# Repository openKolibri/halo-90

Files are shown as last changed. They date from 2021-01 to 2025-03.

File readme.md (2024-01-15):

![wornDynamic]

# HALO-90
A distinct ring of light. An ethereal glow. Patterns that ebb and flow to the music. Ninety lights. All controllable. Powered by a common coin cell. An engrossing look with retro vibes and a modern touch. This is HALO-90.

![presentedCase]

The *HALO* product series, in which these earrings ([HALO-90]) are the first item, is a fully open source electronic jewelery line. It is designed with elegance and wearability in mind. `90` refers to the ninety individually controllable LEDs on the earring face. The built-in compute power is also suitable for creating complex light shows.

This is the technical manual for anyone wanting to modify, hack, remix, or program their own light patterns onto the earrings. The manual goes into fine detail about construction, assembly, and firmware which should encompass all basic knowledge.

## Table of Contents
* [Design](#design)
  + [Hardware](#hardware)
    - [LEDs](#leds)
    - [Microcontroller](#microcontroller)
    - [Battery](#battery)
    - [Microphone](#microphone)
    - [Button](#button)
    - [IMU](#imu)
    - [Passives](#passives)
    - [Alignment Pins](#alignment-pins)
    - [Connectors](#connectors)
  + [Case](#case)
    - [FDM Printed](#fdm-printed)
    - [Cast](#cast)
      * [Mould Master](#mould-master)
      * [Silicone Mould](#silicone-mould)
    - [Stone Casting](#stone-casting)
    - [Magnets](#magnets)
* [Firmware](#firmware)
  + [Modes](#modes)
    - [Dynamic](#dynamic)
    - [Halo](#halo)
    - [Sparkle](#sparkle)
    - [Power Managment](#power-managment)
  + [LED control](#led-control)
  + [Compiling](#compiling)
    - [Ubuntu/WSL](#ubuntu-wsl)
    - [Arch](#arch)
  + [Flashing](#flashing)
    - [Windows](#windows)
    - [Linux](#linux)
* [Absolute Maximum Ratings](#absolute-maximum-ratings)
* [Guaranteed Ratings](#guaranteed-ratings)
* [Manufacturing](#manufacturing)
  + [BOM](#bom)
  + [PCB](#pcb)
  + [PCB Assembly](#pcb-assembly)
    - [Assembly Detail Pictures](#assembly-detail-pictures)
    - [Potential Alternates](#potential-alternates)
  + [Physical Assembly](#physical-assembly)
  + [Production Scaling](#production-scaling)
    - [Case](#case-1)
* [Programmer](#programmer)
* [Artwork](#artwork)
* [Inventory and QC](#inventory-and-qc)
* [Packaging](#packaging)
* [Shipping](#shipping)
* [Safety](#safety)
* [Certifications](#certifications)
* [Licence](#licence)
* [Attribution](#attribution)
  + [Fonts](#fonts)
  + [Libraries](#libraries)
* [ToDo](#todo)

## Design
Design was always a core objective from the very beginning. It *has* to look good. Even more importantly, it must also be functional, as it is a piece of jewelry people are going to wear. If it looks too complex or it's too difficult to use, no one will want to wear it. Comfort was also major goal, as heavy earrings are painful to wear for extended amounts of time, no matter how stunning they are. It's simply not worth the pain.

![render]

The design had to allow for a variety of LED patterns with a range from subtle to attention grabbing. Sensors were added to make light patterns more personal and reactive to the local environment, such as the muted audio responsive pattern. At one moment, befit for a quiet restaurant and later a flashy wide pattern at a concert.

| Audio | Halo | Sparkle |
| --- | --- | --- |
| ![PAT-audio] | ![PAT-halo] | ![PAT-sparkle] |

### Hardware
The electronics are kept minimal for cost reduction and manufacturing simplicity with pads and routing done for all but the IMU and its pull-up resistors. They are not mounted, because there is no firmware support for that and it yields a lower cost variant. The design is done in [KiCad] 5.99 (nightly) and will be ported and set in the stable version. All components and libraries are embedded in the project. 

![IMG-schematic]

The schematic is also available as a [pdf][PDF-schematic]. The layout is done partially programmatically using text manipulation and template stamping using JavaScript and node and then finished up by hand in KiCad. The code is available [here][nodeHaloBuilding].

#### LEDs
There are 90 LEDs that make up the ring, All are regular `0402` red diodes. All the cathodes (K/-) face towards the center of the board, and are placed at `4°` intervals. The LEDS are charlieplexed with ten lines providing individual control. They are run at as high of a current as the battery's internal resistance and GPIO max current allows, so no resistors are used. The red LEDs, with their `2.0 V` - `2.6 V` forward voltage, permits maximizing battery usage
We are using [BL-HUB37A-AV-TRB], because it is low cost and has high availability across multiple vendors in China, but any `0402` LED with a V<sub>f</sub> below `2.7 V`, should yield an equivalent battery life.

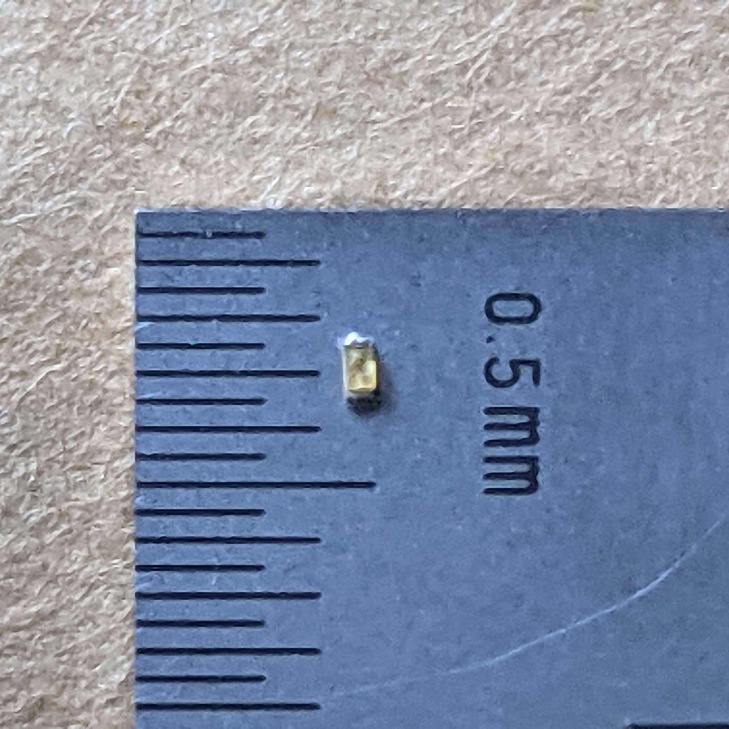
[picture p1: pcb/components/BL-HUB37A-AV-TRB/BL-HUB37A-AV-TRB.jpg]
IMG-BL-HUB37A-AV-TRB


#### Microcontroller
*STMicroelectonics's* [STM8L151G4] acts as the main controller for the earring. The low power microcontroller has a wide range of peripherals, a long expected production life, and low cost and availability in high quantities. Running at its max speed of `16 MHz` is able to easily charliplex the 90 Leds at over `1 kHz`. The `12b ADC` is used to readout the microphone and has plenty of flash (up to `32k`) to store an assortment of light patterns or complex processed designs.

![IMG-STM8L15xxx]

#### Battery
*Linx Technologies's* aptly named [BAT-HLD-001] is a stamped die-cut sheet-metal battery-holder that is as low profile as possible. It is sized for a `CR2032` lithium cell. The metal acts as the anode while the pad on the PCB is the cathode. Battery life varies based on what threshold for brightness you are content with. Over its lifetime, the internal resistance of the battery increases and the voltage decreases. This means that the current possible also decreases and thus the brightness.

![IMG-BAT-HLD-001]

#### Microphone
The microphone selection was rather difficult due to a lack of specifications available with amplified MEMS microphones. *Knowles* [SPW2430HR5H-B] was selected, as it seemed reasonable and could be tested with Adafruits breakout board fairly easily.

![IMG-SPW2430HR5H-B]

Using a built-in amplified MEMS microphone decreases the number of component placements and simplifies layout and verification, at the expense of not having instrumentation knowledge of your audio response.

#### Button
*C&K* [KXT3] series provides ultra low profile miniature tactile switches and we chose `KXT311LHS`, with a low actuation force of `100g`. It can be easily pressed with the edge of your nail, or a bit less comfortably with the back.

The button provides the functionality of changing light patterns by pressing and triggering it into a low power sleep mode by holding for `500 ms`. Completely available as an interrupt to the microcontroller, so other uses can be implemented. 

![IMG-KXT3]

#### IMU
[LSM6DSM] is a 6DOF IMU with a three-axis accelerometer and three-axis gyroscope by *STMicroelectronics*. It communicates over I2C and is connected to the hardware I2C peripheral in the microcontroller. It allows a fast data stream at very low power. It also has additional low power modes and the ability to wake the main microcontroller over interrupt with the routed interrupt pin. 

![IMG-LSM6DSM]

#### Passives
There are three passives (five if the IMU is populated) that can be of any tolerance. There are two `1 uF` and `0.1 uF` decoupling capacitors and one `10k` pull-up on the reset of the processor. The two IMU pull-ups are `10k` I2C pull-ups.

#### Alignment Pins
There are four tooling holes/alignment pins that can be used for add-ons. They are `1.152 mm` (`45.35 mil`) in diameter and are placed `2.8 mm` and `5.5 mm` from the center.

![alignmentPins]

 The earring is `24 mm` in diameter, has a mass of `5.207 g` (`2.135 g` without the battery) and the top eyelet extends `2 mm` extra, yielding a bounding box of `24 mm x 26 mm x 6.36 mm`.

![mass]

#### Connectors
The only connectors on the board are six `⌀ 1 mm` copper circles that are exposed as contacts for spring pins. They are placed evenly across the board so it receives balanced forces from the custom programmer (or testing jig).

| Labels | Dimensions |
| --- | --- |
| ![pgrmPads] | ![pgrmPlacement] |

The labeled pins have their descriptions in the table below.

| Pin  | Description |
| ---- | --- |
| 3V0  | Connected to Batt+ and power net |
| GND  | Connected to ground net |
| TX | GPIO PB2 for serial out | 
| RX | GPIO PB4 for serial in | 
| RST  | Active low, 10k pull-up | 
| SWIM | Programming interface | 

### Case
The case holds the earrings and two cells in its cavities. This allows for the storing and organizing of at least 36 hours of available runtime. The earring case consists of two pieces held together with magnets. The cavities inside the case hold all components securely so that they do not rattle. The earrings are displayed beautifully when the case is opened.

![cases]

The case is designed in CAD and made to house two earrings (with or without batteries inserted) as well as two additional batteries. All of the edges are filleted and the closed case is comfortable when held. One corner is chamfered which makes it easier to align both pieces together in the correct orientation, and the magnets are oriented to resist trying to close it whenever the directionality does not match. It also provides a very satisfying tactile click when they align and close.

![caseRender]

#### FDM Printed
The first sets of cases are made of 3D printed plastic PLA. The top and bottom have bold contrasting colors that uniquely identify the brand. They are printed with a `20%` gyroid infill and at `200 um` layer height. The 3D models must be scaled up to `100.2%` to account for PLA shrinkage. 

![caseFDM]

#### Cast
For a more bold and distinctive style with a pebble or smooth seashell-like finish, casted cases provides an air of luxury using distinctive materials.

![caseBatch]

##### Mould Master
Moulding masters were made using the same 3D printed designs, printed at an `80 um` layer height, and then repeatedly filled, primed, and sanded with `P400` to `P3000` grit sandpaper on top of a glass plate to keep the straight faces square. This fills all of the air gaps and allows for a very smooth finish. It is then buffed to a shine with nail buffer sponges.

![caseMaster]

##### Silicone Mould
A platinum cure shore `A20` silicone rubber (Troll Factory [TYP-1]) is used to make a mould of the master. This has an accuracy of `~2 um` so it's able to reproduce a surface finish. Since the back is flat, an open-faced mould is made. The part, as well as the walls, are held in place with [Quakehold] museum wax, and mixing the exact amount of silicone needed (based on a CAD model) means a high yield. After curing, the mould box walls are cut off and the master is demoulded, yielding a silicone mould.

![caseMould]

#### Stone Casting
The mould can be cast with various materials, including other silicones, polyuretane, rubbers, and resins. In our case, we used plaster. We are using high compressive strength *Ernst Hinrichs* [Sockelgips FL] `Type-4 low expansion dental plaster`. These plasters have a thixotropic agent that allows them to flow better, which means that they mix thinner and reproduce in finer detail. Applying a surfactant to the mould, mixing with distilled water, and using a vibrating table produces castings with fewer bubbles. The back is roughly leveled off and set to cure. The part is demoulded and the back is hand finished with `P320-P3000` grit sandpaper.

![caseCasting]

After 24 hours, the part has cured to its final hardness and has dried out completely. It can then be processed further with magnets and dye. 

#### Magnets
The magnets are `6 mm x 1 mm` `N52` neodynium magnets that are glued in with UHU Max Repair Extreme adhesive. They are coated in `Ni-Cu-Ni`, at around `12 um`. The magnets are a very tight fit in their countersinks and are glued in to fit securely. They have a fixed orientation between both parts made, so swapping tops or bottoms with other sets is possible. There are few adhesives that work well when bonding two materials together that are already difficult to glue.

![6x1-magnets]

Magnets are installed using a gluing jig. One jig for the top and one for the bottom. Both jigs have magnets installed to correct for orientation when gluing. The jigs also have a matching chamfer which prevents the wrong part from being placed or placing the part backwards by accident.

![magnetsGlued]

The two jigs are color-coded as well. Adhesive is dispensed into the wells and the magnet is dropped, which automatically orients itself with the jig magnet. It can then be removed and set to cure.

![magnetJig]

## Firmware
The firmware is coded at the register level in C. The code is fully interrupt-based and performs quite efficiently. The toolchain is simple and built on open source tools. This makes it harder to code, but allows for significant optimization.
 
### Modes
There are multiple modes available on the halo earring that can be switched through when pressing the button. Each press of the button cycles to the next mode, eventually circling back around.

| Audio | Halo | Sparkle |
| --- | --- | --- |
| ![GIF-audio]  | ![GIF-halo] | ![GIF-sparkle] |

#### Dynamic
The mode selected on startup is the audio-based dynamic mode. During every ADC cycle it reads the analog value and projects the audio waveform amplitude, based around a moving point on the ring with wrap around.

![PWR-audio]

Power profile readings show no correlation with audio level, and an `11.71 mA` power consumption with `105 uA` standard deviation. Projected battery life with a `220 mA` CR2032 cell is ~18.8 hours.

#### Halo
In the HALO mode, the entire light ring is lit. This is done through interlacing the illumination of each LED. The deep sleep auto wakeup timer is set to wake up every two clock cycles of the low speed `32 kHz` oscillator. On every wake, it changes to illuminate the 13th following LED, wrapping around at 90.

```c
setLed((prevLed + 13)%90);
```

This allows for a cleaner and more consistent scan over the entire halo ring since 13 is the greatest integer factor (besides 91), for all of the LEDs to be turned on evenly around the ring. Greater spacing causes *frames* to interlace with one another, resulting in a cleaner visual experience.

![PWR-halo]

Power profile readings show a `10.88 mA` power consumption with `60 uA` standard deviation. Projected battery life with a `220 mA` CR2032 cell is ~20.2 hours.

#### Sparkle
Sparkle mode is the best for minimal power draw and is implemented in a single line of code. At `~320 Hz`, the processor wakes from deep sleep and runs the selection of which LED to light (if any).

```c
rand()%15 ? ledLow(prevLed) : setLed(rand() % 90);
```

Given a 1/15 chance, a random LED will light up. Otherwise, any previously lit LEDs will be turned off. This results in a more visually pleasing pattern over just randomly lighting LEDs, which produce sharper bursts of light. Since the processor is only awake `0.002%` of the time, and the LED has a chance of being on only `6.6%` of the time, the power consumption is quite minimal. 

![PWR-sparkle]

Power profile readings show a `2.01 mA` power consumption with `327 uA` standard deviation. Projected battery life with a `220 mA` CR2032 cell is ~109.5 hours, (over 4.5 days).

#### Power Managment
Pressing and holding the button for `500 ms` will turn off all LEDs and put the cpu into deep sleep mode. In this mode the current draw is around `15 uA` and the only wake interrupt is the button press.

![GIF-boot]

Pressing and holding the button will show a boot-up animation that lights up in a ring around the face. Holding the button until it makes a full revolution, about one second, will trigger a software reset of the halo, turning it back on.

### LED control
Since the LEDs are configured in a charlieplex array, only one LED can be on at a time. Some optimization can allow multiple LEDs to light simultaneously, but at a cost of consistency in brightness and power draw. There are two low-level functions that can turn a individual LED on or off, as well as a helper function that remembers the last LED and turns it off before turning on the next one.

```c
void setLed(uint8_t led);
void ledHigh(uint8_t led);
void ledLow(uint8_t led);
```

The function to get the column and row from the LED number is shown below:
```c
uint8_t col = led / 9;
uint8_t topElements = 9 - col;
uint8_t row = 9 - (led % 9);
if (topElements <= (9 - row)) {
  row--;
}
```

To turn the LEDs off, the column and row are both set to high impedance. To turn it on, the column is set high and the row is set low.

The previous LED *must* be turned off before lighting up the next LED or else there is a risk of damaging the electronics. It is recommended to only use the `setLed` and `ledLow` functions.

### Compiling
Compiling is done with the [SDCC] ("Small Device C Compiler") and the included makefile.

As an example, the following steps are given for some systems but should easily be transferable to the distro of your choosing. The requirements are `make` and `sdcc`. They should both be available in the path. Once installation is completed, running `make` will generate the `halo.ihx` file, which is the binary to be flashed.

```bash
make
```

#### Ubuntu/WSL
```bash
sudo apt install -y make
sudo apt install -y sdcc
```
#### Arch
```bash
sudo pacman -S make
sudo pacman -S sdcc
```

### Flashing
Some form of flashing software is required, along with a programmer that can program over the `SWIM` protocol. We are using third party `STLink-V2` clones, because the form factor of the genuine programmer is difficult to use and newer programmers do not support `SWIM`.

#### Windows
`STVP_CmdLine` is required as the flashing software and comes with the software package [ST Visual Programmer]. This needs to be installed and `c/Program Files (x86)/STMicroelectronics/st_toolset/stvp/STVP_CmdLine.exe` needs to be added into the path.

Once it's installed, it can be run with the following flags. Preferably in WSL but should also be possible in CMD or PS.

```bash
STVP_CmdLine.exe -Device=STM8L15xG4 -FileProg=halo.ihx -verif -no_loop -no_log
```

It is also incorporated into the make file and can be run with the following:

```bash
make flash
```

#### Linux
[STM8 Flash] is an open source `SWIM` compatible flashing utility for linux. The tool is built from source. Short instructions are written below.

```bash
git clone https://github.com/vdudouyt/stm8flash.git
cd stm8flash
make
sudo make install
```

Flashing can then be done with the following command:

```bash 
stm8flash -cstlink -pstm8l151 -w halo.ihx
```

It is also incorporated into the make file and can be run with the following:

```bash
make flash
```

## Absolute Maximum Ratings

| Parameter | Min  | Max | Unit |
| --- | ----:| ---:| ---- |
| Battery Voltage | -0.3 | 3.6 | Volt |
| Temperature |  -40 |  85 | °C |
| Power Draw |  15u | 25m | Amp  |

## Guaranteed Ratings

| Parameter | Min | Max | Unit |
| --- | ---:| ---:| ---- |
| Battery Voltage | 1.8 | 3.6 | Volt |
| Operating Temperature  | -20 |  50 | °C |
| Storage Temperature | -40 |  85 | °C |

The earrings should be fine to leave in a hot car (although the 3D printed plastic case could warp). If you are outside of these ratings, take care of yourself, you are either freezing or at risk of heat stroke. The earrings will be fine.

## Manufacturing
Although taking on novel uses of materials, the ability to manufacture at scale was always a primary focus. Parts were selected with strong supply chains and alternatives. Layout was designed with generous rules to accommodate for as many fabs as possible and the number of unique components was minimized. The microphone and battery holder are from single vendors but they have proven track records and well-known supply chains. Alternatives to be tested are still proposed.

### BOM
The BOM was selected with parts that are common to the high-volume Chinese manufacturing market, have strong supply chains, and have many alternatives available in case a supplier stops manufacture or supply dips occur. The number of unique parts was kept to a minimum and the maximum amount of features can be implemented with "free" pins, like the programming SMD pads. The table of BOM is shown below.

| REF | QTY | Manufacturer | MPN | Description |
| --- | ---:| --- | --- | --- |
| D1-D90 |  90 | Brightled | BL-HUB37A-AV-TRB | LED: RED 627-637nm 50mcd@20mA 0402  |
| U1 | 1 | STMicroelectronics | STM8L151G4U6 | MCU: 8b 16MHz 16k Flash UQFN-28-4x4 |
| MK1 | 1 | Knowles Electronics | SPW2430HR5H-B | MIC: Omni Si-Sonic 3.1x2.5x1.0mm |
| BT1 | 1 | Linx Technologies | BAT-HLD-001 | BAT: CR2032 Cell Holder |
| S1 | 1 | C&K | KXT311LHS | SW: Low Profile 3x2x0.6mm 100gf |
| R3 | 1 | Uniroyal | 0402WGF1002TCE | RES: 10k 5% 1/16W 0402 |
| C1 | 1 | Samsung Electro-Mechanics | CL05B104KO5NNNC  | CAP: MLCC 100nF 16V 0402 |
| C2 | 1 | Samsung Electro-Mechanics | CL05A105KA5NQNC  | CAP: MLCC 1uF 25V 0402 |

The [csv][BOMcsv] is provided with the sources.

### PCB
There is a single PCB. Although still common, some of the more precise requirements were needed to end up with a printed circuit board small enough.

| Parameter | Value | Unit |
| --- | -----:| ---- |
| Height | 26 | mm |
| Width | 24 | mm |
| Layers | 4 | ul |
| Copper | 1.0 | oz |
| Copper Inner | 0.5 | oz |
| Thickness | 1.0 | mm |
| Material | FR4 | ul |
| Min Drill | 0.2 | mm |
| Trace Size | 5/5 | mil  |
| Mask | Black | ul |
| Silk | White | ul |
| E-Test | Yes | ul |
| Surface Finish | ENIG  | ul |

The PCB has four layers.

| Front | Inner 1 | Inner 2 | Back |
| --- | --- | --- | --- |
| ![Layer0] | ![Layer1] | ![Layer2] | ![Layer3] |

### PCB Assembly
The whole board can be pick and placed. The table below shows some data that might be needed when requesting a quote.

| Parameter | Value |
| --- | -----:|
| Unique Parts | 8 |
| SMD Parts | 8 |
| Placements | 97 |
| Solder Joints | 222 |
| Front Components  | 96 |
| Back Components | 1 |

The smallest components are `0402` LEDs, and all parts can survive normal lead-free re flow profiles. The microphone is open port MEMS so do not wash, clean, or expose it to ultrasonic vibrations (datasheet has further requirements).

#### Assembly Detail Pictures

| Assembly | Front |
| --- | --- |
| ![assembly] | ![front] |

| Front Detail | Back Detail |
| --- | --- |
| ![frontDetail] | ![backDetail] |

| Front ISO | Back ISO |
| --- | --- |
| ![frontIso] | ![backIso]  |

#### Potential Alternates
Some alternates have not been tested, but their specifications match.

| Stated | Alternative | Tested |
| --- | --- | --- |
| SPW2430HR5H-B | ZILLTEK ZTS6016  | No |
| BAT-HLD-001 | MY-2032-08 | No |
| STM8L151G4U6 | STM8L151G6U* | Yes |

*To be updated when I can get stock or have to switch suppliers*

### Physical Assembly

The earwire is attached with jewelry pliers through the hole. The 1mm hole is made for up to `0.8 mm` wire over `20 ga`. Gold plated french hooks are used. these are commonly available as jewelry findings.

![IMG-frenchEarwire]

### Production Scaling Boards
The board can be hexagonally packed into a panel with tiny tabs since it's held on all sides. To increase production efficiency, only one side can be PnP and the battery holder is added afterwards by hand.

![hexPackedPanel]

#### Production Scaling Cases
The master moulds can create secondary masters out of resin which could then be used to make gang moulds, allowing for multiple castings in parallel. 

![gangMoulds]

## Programmer
The programmer has a hole at the top to allow a pin to push the button for testing.

![programmer]

The 3D printed base holds the board in place while the PCB is held to it with 3mm heat set inserts. The PCB acts as a compliant mechanism providing down pressure while still allowing it to be flexible enough to lift. 

The programmer uses *Mill-Max* ‎‎‎[0965-0-15-20-80-14-11-0]‎ spring pins on a PCB that matches exactly with the six pads on the face of the board. 

![springPins]

The top part is lifted up and the assembled board is slipped in. The spring force from the PCB pushes back down on to the pads and can then be left for programming and debugging.

## Artwork
The design and layout, the main artwork on the board and the PCB layers and traces, are *NOT* protected Intellectual Property ("IP"), see LICENSE files for appropriate details.
Any additional writing or images such as the Kolibri bird, copyright and designer notices, and certifications *ARE* considered protected IP and notice is given that they are protected by all applicable IP laws.
The below "Getting Started" card also has artwork which is considered protected IP and is copyrighted with all rights reserved.

| Front | Back |
| --- | --- |
| ![cardFront] | ![cardBack] | 

## Inventory and QC
Inventory can be managed with QR coded serialized tags. This serialization provides better quality control because it allows failure analysis and tracking in cases of issues traceable to batch and assembly.

## Packaging
We are packaging and shipping in `14 cm x 17 cm` padded envelopes with branded stampings. These fit under the Warenpost requirements and allow international shipping. The envelopes are verified to be under `3 cm` before dispatching. Custom labeled sleeves will be used for retail packaging.

## Shipping
The labels are printed with CN22 on the harmonized label schedule.

Lithium cells have special requirements for shipping. With air mail, small cells (up to four) are packaged securely and may be sent with the product. A note (`Lithium metal batteries in compliance with Section II of PI969`) is required on the packaging, but no warning label is mandatory.

For international shipping, the HS code `7117.90.0000	Imitation Jewlery other` is used.

## Safety
The edges are fully routed when possible or finished afterwards. The PCB is made from fiberglass so care must be taken because it can have abrasive edges. Clear coat nail polish can be applied to round and soften the edges without changing how it looks.

The `CR2032` cells are quite safe, as they have only very small traces of lithium, and have a fairly high internal resistance. However, they must still be disposed of responsibly. `LIR2032` or other rechargeable 2032 cells should *not* be used because they have a higher voltage outside of the guaranteed parameters and significantly lower capacity (under 25%).

If the battery is placed in backwards, it will drain over time because there is no reverse polarity protection. It will heat up but should not damage anything, due to high internal resistance limiting the discharge. The low voltage, `3.0 V`, as well as the currents used pose very little risk.

The printed circuit boards are assembled in a lead-free process, and all components are `ROHS` certified.

## Certifications
Certifications take time and effort but will make a better product by guaranteeing its safety to users and letting them use it in other projects. The table below shows the order in which we will obtain certifications.

| Certifying Authority | Status |
| ---| --- |
| OSHW | [DE000103] |
| CE | No  (Self Certification)  |
| FCC | No  (Self Certification)  |
| WEEE | No  (yearly fee) |

## Licence
The product was designed by Sawaiz Syed for Kolibri. Kolibri owns all protected IP. Everything that is not otherwise stated as being protected IP (e.g. firmware, PCB design, documentation) is released under permissive copyleft licenses.

| Sector | License | Version |
| --- | --- | ---:|
| Hardware | [CERN-OHL-S] | 2.0 |
| Firmware | [GNU GPL] | 3.0 |
| Documentation | [CC BY-SA] | 4.0 |

Files of all licenses are required with the distribution of files. All files are available in easy-to-modify formats for remixing. 

---
#### Please purchase original products from [Kolibri] to support further products, design, and research :)

---

## Attribution
- Make
- [SDCC]
- KiCad
- [STM8Flash]
### Fonts
- [Nunito]
- [IBM PLEX Mono]
- [DejaVu] 
### Libraries
- [STM8 Headers] Copyright (c) - 2020 Georg Icking-Konert

## ToDo
- [ ] Led sometimes remains on after shutdown
- [ ] Randomly HALO pattern forms high low pattern 

<!--                       References                                      -->
<!-- Files -->
[BAT-HLD-001]:                ./pcb/components/BAT-HLD-001/BAT-HLD-001.pdf
[BL-HUB37A-AV-TRB]:           ./pcb/components/BL-HUB37A-AV-TRB/BL-HUB37A-AV-TRB.pdf
[KXT3]:                       ./pcb/components/KXT3/KXT3.pdf
[LSM6DSM]:                    ./pcb/components/LSM6DSM/LSM6DSM.pdf
[SPW2430HR5H-B]:              ./pcb/components/SPW2430HR5H-B/SPW2430HR5H-B.pdf
[STM8L151G4]:                 ./pcb/components/STM8L15xxx/STM8L15xxx.pdf
<!-- Links -->
[HALO-90]:                    https://openkolibri.com/hlo/90
[KiCad]:                      https://kicad.org/
[ST Visual Programmer]:       https://www.st.com/en/development-tools/stvp-stm32.html
[Quakehold]:                  https://www.quakehold.com/collectibles.html
[TYP-1]:                      https://trollfactory.de/produkte/silikon-kautschuk/haertegrad-shore/weich-shore-a25/7044/tfc-silikon-kautschuk-typ-1-abformsilikon-weich-1-1-nv-troll-factory-rtv
[0965-0-15-20-80-14-11-0]:    https://www.mill-max.com/products/pin/0965
[Sockelgips FL]:              https://www.hinrichs-dental-shop.de/sockelgips-fl-p-1469.html
[Kolibri]:                    https://openkolibri.com/
<!-- Internal Links -->
[PDF-schematic]:              ./docs/design/hardware/schematic.pdf        
[nodeHaloBuilding]:           ./pcb/halo.js
[BOMcsv]:                     ./pcb/bom.csv
<!-- Intro -->
[wornDynamic]:                ./docs/intro/wornDynamic.gif                              "Worn earring reacting to music Model: Greta"
[presentedCase]:              ./docs/intro/haloSetDisplay.jpg                           "Pair of earings in holder"
[render]:                     ./docs/render.jpg                                         "Render of earrings showing propertions"
<!-- Design -->
[PAT-audio]:                  ./docs/patterns/audio.gif                                 "Worn animation of audio pattern"
[PAT-halo]:                   ./docs/patterns/halo.gif                                  "Worn animation of halo pattern"
[PAT-sparkle]:                ./docs/patterns/sparkle.gif                               "Worn animation of sparkle pattern"
<!-- Hardware -->
[IMG-schematic]:              ./docs/design/hardware/schematic.png                      "Image of schematic"

<!-- Components -->
[IMG-BAT-HLD-001]:            ./pcb/components/BAT-HLD-001/BAT-HLD-001.jpg              "CR2032 Battery Holder"
[IMG-BL-HUB37A-AV-TRB]:       ./pcb/components/BL-HUB37A-AV-TRB/BL-HUB37A-AV-TRB.jpg    "0402 Red LED"
[IMG-KXT3]:                   ./pcb/components/KXT3/KXT3.jpg                            "Miniature low profile button"
[IMG-LSM6DSM]:                ./pcb/components/LSM6DSM/LSM6DSM.jpg                      "6 axis IMU"
[IMG-SPW2430HR5H-B]:          ./pcb/components/SPW2430HR5H-B/SPW2430HR5H-B.jpg          "MEMS Microphone"
[IMG-STM8L15xxx]:             ./pcb/components/STM8L15xxx/STM8L15xxx.jpg                "Low power microcontroller"
[IMG-frenchEarwire]:          ./pcb/components/frenchEarwire/frenchEarwire.jpg          "Gold plated french earwire"
<!-- Magnets -->
[6x1-magnets]:                ./docs/components/magnets.jpg                             "6mm x 1mm N53 disc mangents"
[magnetsGlued]:               ./docs/assembly/jigsGlue.jpg                              "Mangents glued using the jig"
[magnetJig]:                  ./docs/assembly/jigs.jpg                                  "Jigs used to glue magnets into place in the correct orentation"
<!-- Connectors and pads -->
[alignmentPins]:              ./docs/connectors/pinDim.jpg                              "Holes for tooling and jig alginment"
[mass]:                       ./docs/connectors/mass.jpg                                "Halo and battery on scale for measuring mass"
[pgrmPads]:                   ./docs/design/hardware/pgrmPads.png                       "Labeling of the programming pads"
[pgrmPlacement]:              ./docs/design/hardware/pgrmPlacement.png                  "Dimentions of the programming pads"
[springPins]:                 ./docs/components/springPin.jpg                           "Spring pin for programing"    
<!-- Case -->
[caseBatch]:                  ./docs/case/batch.jpg                                     "Batch of cast cases"
[caseRender]:                 ./docs/case/caseRender.jpg                                "Render of case looking at coloring options"
[cases]:                      ./docs/case/cases.jpg                                     "View of diffrent colour and dye trials"
[caseCasting]:                ./docs/case/casting.jpg                                   "Closeup of cast case"
[caseFDM]:                    ./docs/case/fdmPrinted.jpg                                "View of multiple FDM printed cases"
[caseMaster]:                 ./docs/case/master.jpg                                    "Master showing PLA, and primer, anded to a finsih"
[caseMould]:                  ./docs/case/mould.jpg                                     "Mould ready for pouring"
<!-- Firmware -->
[PWR-audio]:                  ./docs/firmware/powerProfile/audioPowerProfile.png        "Current vs time capture in audio mode"
[PWR-halo]:                   ./docs/firmware/powerProfile/haloPowerProfile.png         "Current vs time capture in halo mode"
[PWR-sparkle]:                ./docs/firmware/powerProfile/sparklePowerProfile.png      "Current vs time capture in sparkle mode"
[GIF-audio]:                  ./docs/firmware/powerProfile/audio.gif                    "Animation showing audio mode"
[GIF-halo]:                   ./docs/firmware/powerProfile/halo.gif                     "Animation showing halo mode"
[GIF-sparkle]:                ./docs/firmware/powerProfile/sparkle.gif                  "Animation showing sparkle mode"
[GIF-boot]:                   ./docs/firmware/boot.gif                                  "Animation showing booting mode"
<!-- PCB Layers -->
[Layer0]:                     ./docs/layers/L0.png                                      "Front layer"
[Layer1]:                     ./docs/layers/L1.png                                      "Inner 1 layer"
[Layer2]:                     ./docs/layers/L2.png                                      "Inner 2 layer"
[Layer3]:                     ./docs/layers/L3.png                                      "Back layer"
<!-- PCB Assembly -->
[assembly]:                   ./docs/pcbAssembly/assemblyDraw.png                       "Drawing showing led and chip orentations"
[backDetail]:                 ./docs/pcbAssembly/back-detail.jpg                        "Detail view of back assembled"
[backIso]:                    ./docs/pcbAssembly/back-iso.jpg                           "Isometric view of assembled back"
[frontDetail]:                ./docs/pcbAssembly/front-detail.jpg                       "Detail view of assembled front"
[front]:                      ./docs/pcbAssembly/front-full.jpg                         "Front view of assembled board"
[frontIso]:                   ./docs/pcbAssembly/front-iso.jpg                          "Isometric view of front assembled"
[hexPackedPanel]:             ./docs/pcbAssembly/hexPackedPanel.png                     "Panel with 35 boards"
<!-- Programmer -->
[programmer]:                 ./docs/programmer.jpg                                     "View of programmer and it's componets"
<!-- Artwork -->
[cardFront]:                  ./docs/artwork/cardFront.png                              "Getting started card front"
[cardBack]:                   ./docs/artwork/cardBack.png                               "Getting started card back"
<!-- Certifications -->
[DE000103]:                   https://certification.oshwa.org/de000103.html
<!-- Licence -->
[CERN-OHL-S]:                 ./pcb/LICENSE
[GNU GPL]:                    ./firmware/LICENSE
[CC BY-SA]:                   ./docs/LICENSE
<!-- Attribution -->
[STM8Flash]:                  https://github.com/vdudouyt/stm8flash
[STM8 Headers]:               https://github.com/gicking/STM8_headers
[SDCC]:                       http://sdcc.sourceforge.net/
<!-- Fonts -->
[DejaVu]:                     https://dejavu-fonts.github.io/
[IBM Plex Mono]:              https://www.ibm.com/plex/
[Nunito]:                     https://github.com/vernnobile/NunitoFont

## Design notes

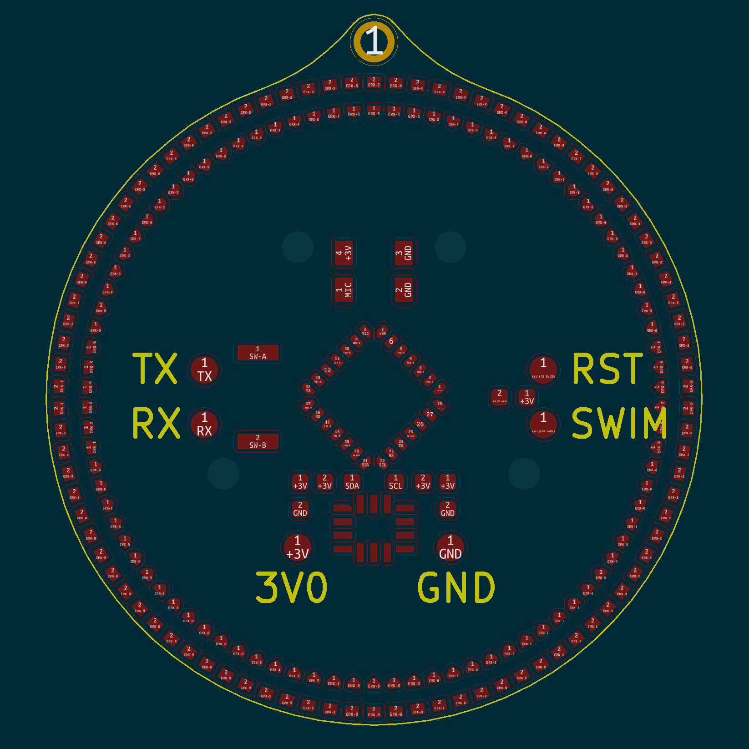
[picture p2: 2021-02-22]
docs/design/hardware/pgrmPads.png

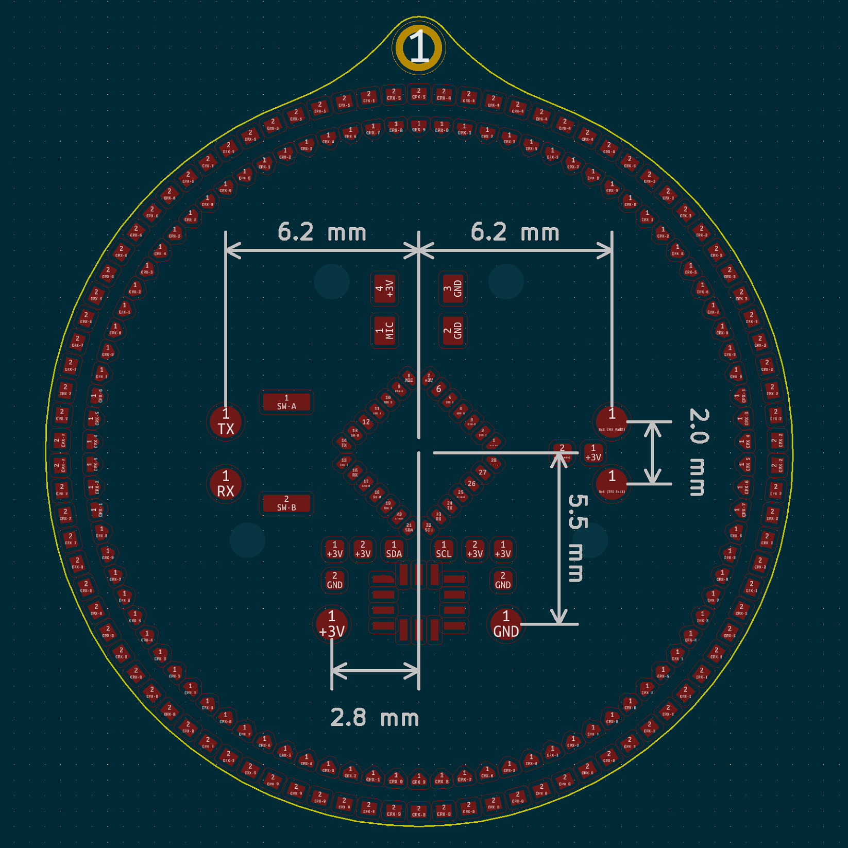
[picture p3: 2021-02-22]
docs/design/hardware/pgrmPlacement.png

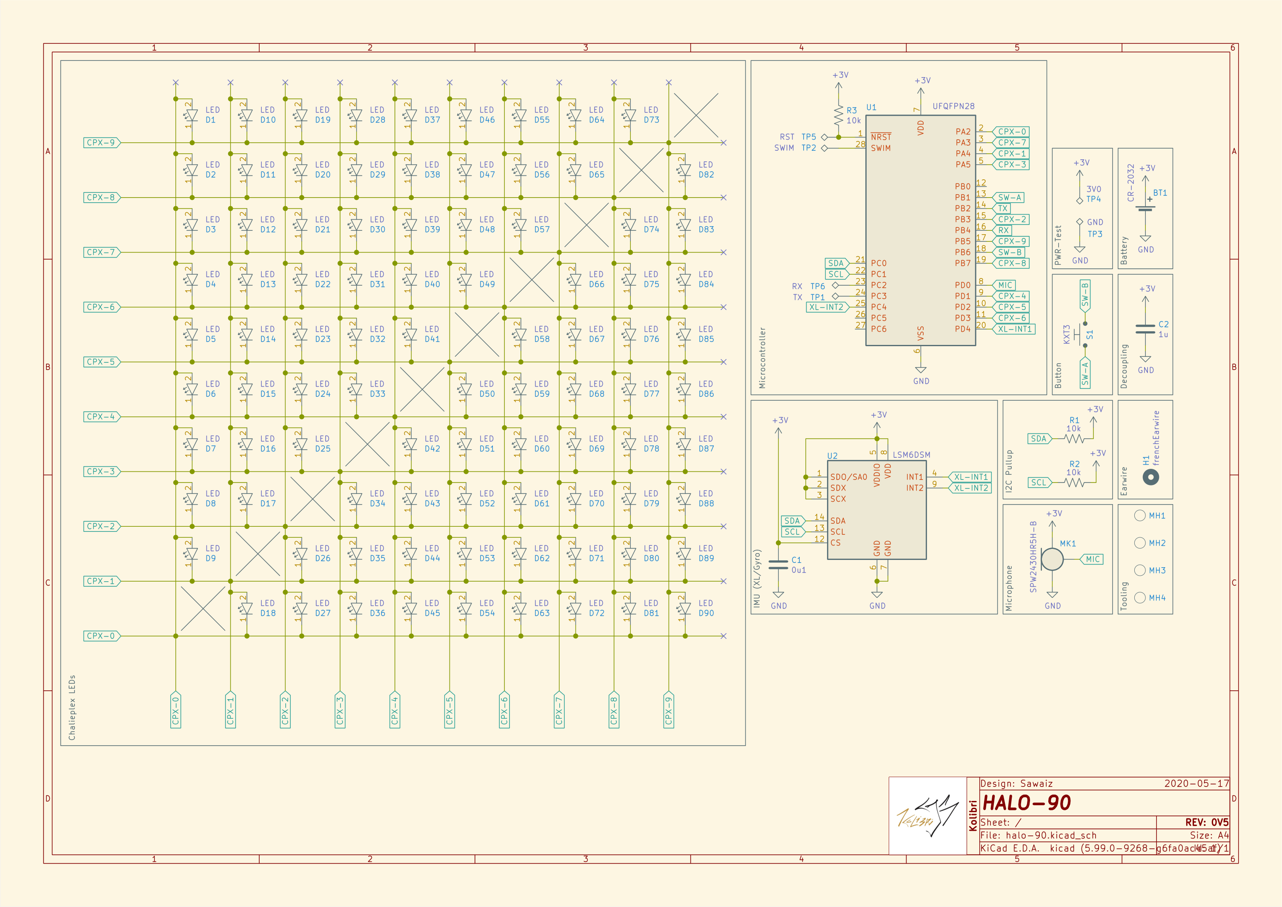
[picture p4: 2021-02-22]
docs/design/hardware/schematic.png

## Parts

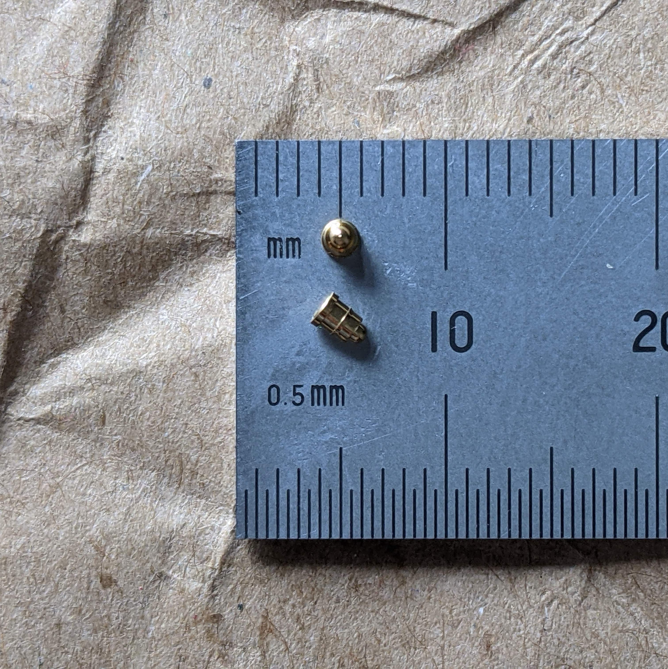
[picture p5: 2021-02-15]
docs/components/springPin.jpg

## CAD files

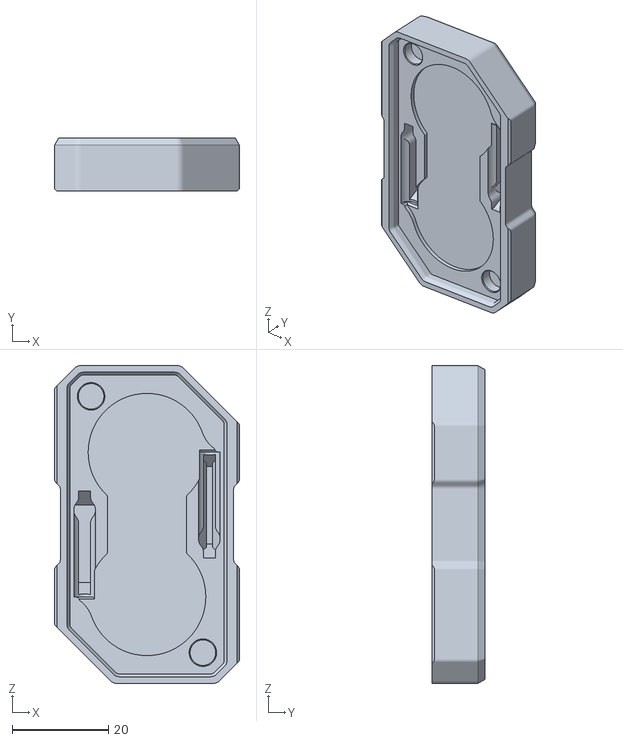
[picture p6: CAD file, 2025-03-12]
case/Case_Top_FishHook.STL
38.4 x 11.0 x 66.0

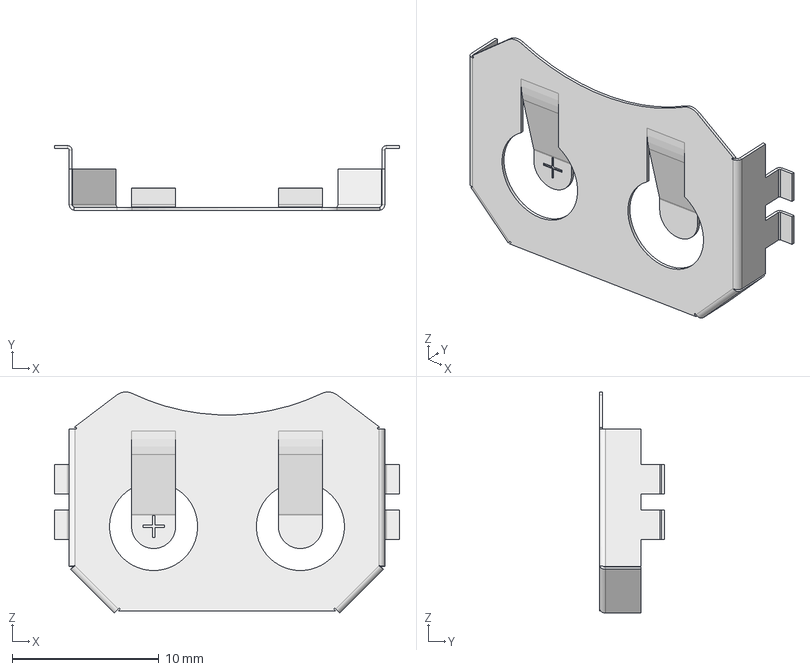
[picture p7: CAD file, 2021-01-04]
pcb/components/BAT-HLD-001/BAT-HLD-001.stp
23.5 x 4.40 x 15.1 mm

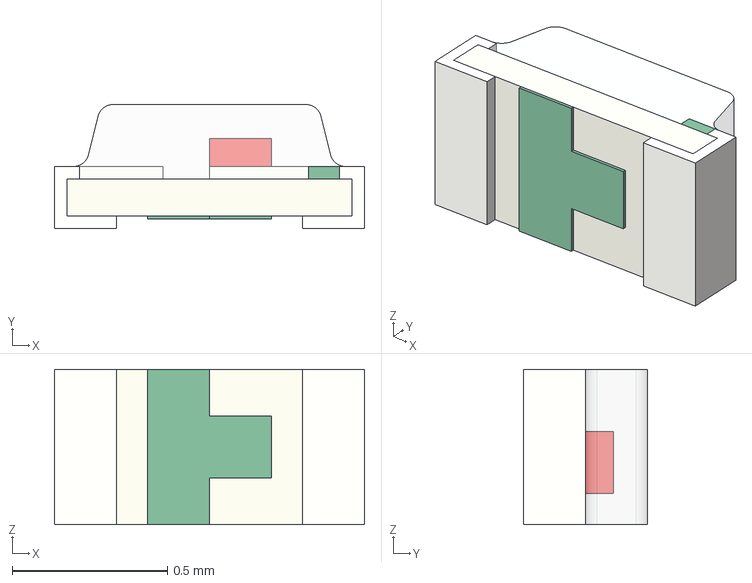
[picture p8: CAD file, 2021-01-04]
pcb/components/BL-HUB37A-AV-TRB/BL-HUB37A-AV-TRB.stp
1.00 x 0.4 x 0.5 mm

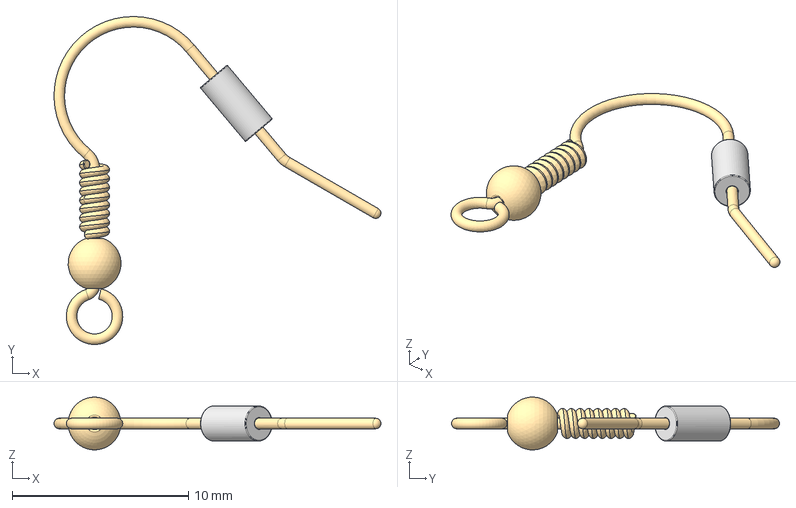
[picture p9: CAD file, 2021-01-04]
pcb/components/frenchEarwire/frenchEarwire.stp
18.5 x 18.6 x 2.99 mm
HAKEN_1_1
KUGEL_1_1
FEDER_1_1
FIXIERSCHLAUCH_1_1

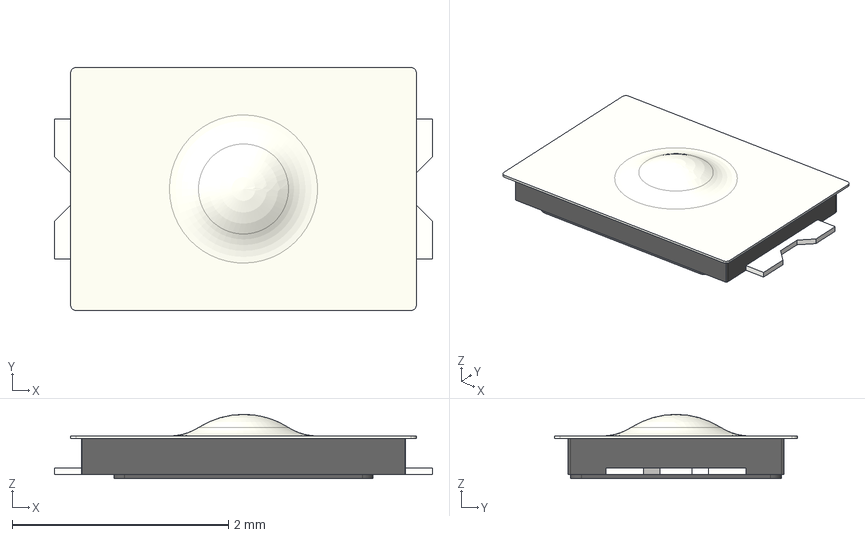
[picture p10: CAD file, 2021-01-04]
pcb/components/KXT3/KXT3.stp
3.50 x 2.25 x 0.595 mm

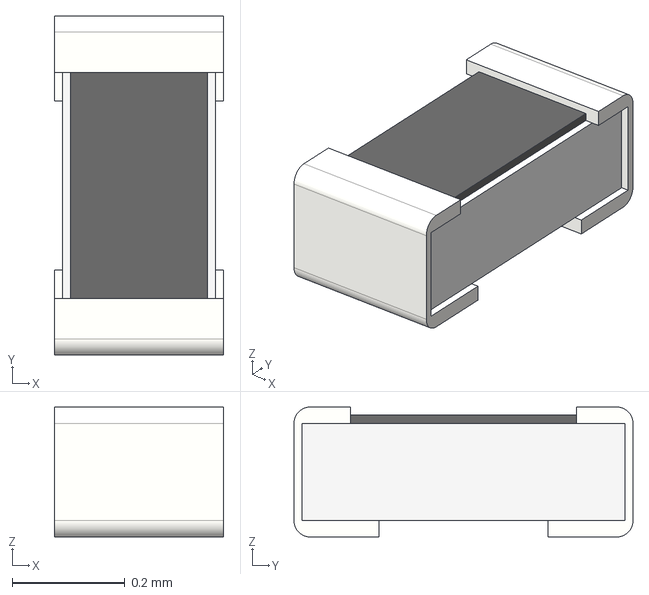
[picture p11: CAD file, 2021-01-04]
pcb/components/passives/R-0201.stp
0.3 x 0.6 x 0.23 mm

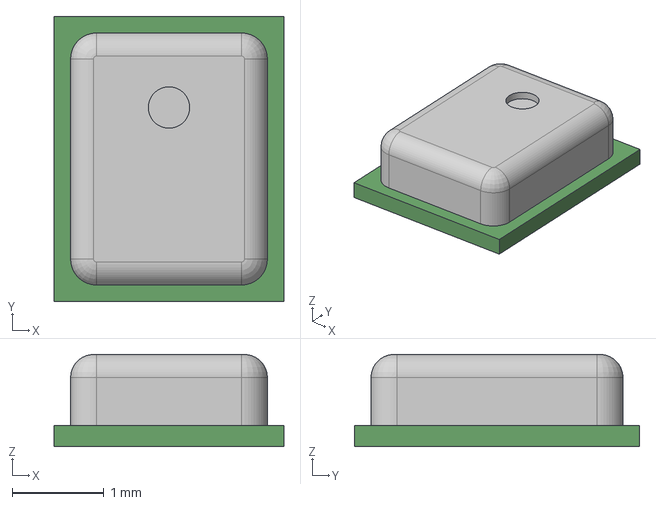
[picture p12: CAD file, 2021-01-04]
pcb/components/SPW2430HR5H-B/SPW2430HR5H-B.step
2.50 x 3.10 x 1.00 mm

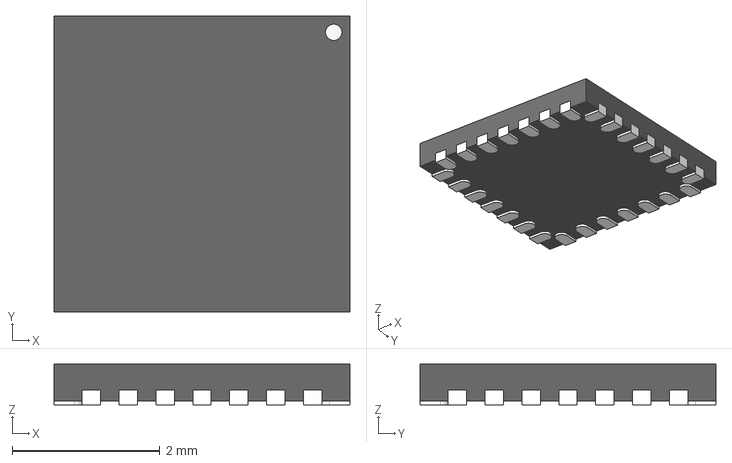
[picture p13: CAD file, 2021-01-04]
pcb/components/STM8L15xxx/UFQFPN28.stp
4.00 x 4.00 x 0.55 mm

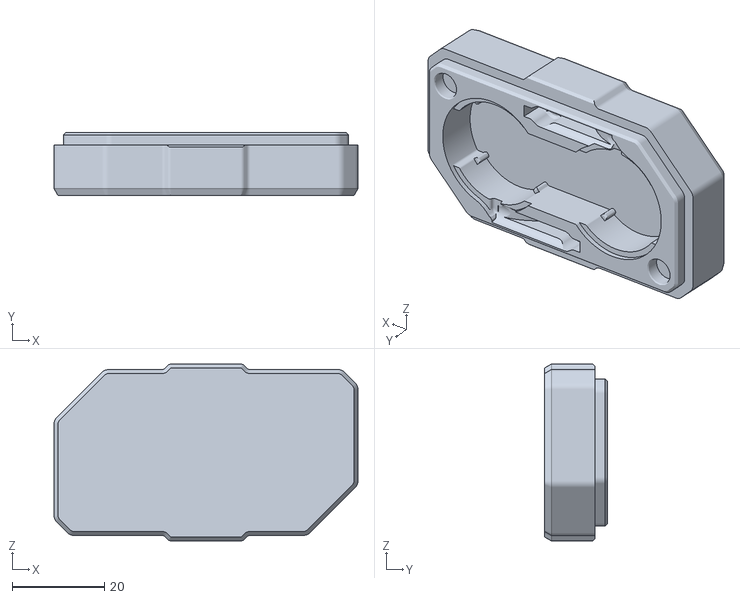
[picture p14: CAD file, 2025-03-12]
case/Cast_Bottom_FishHook.STL
66.0 x 13.7 x 38.4

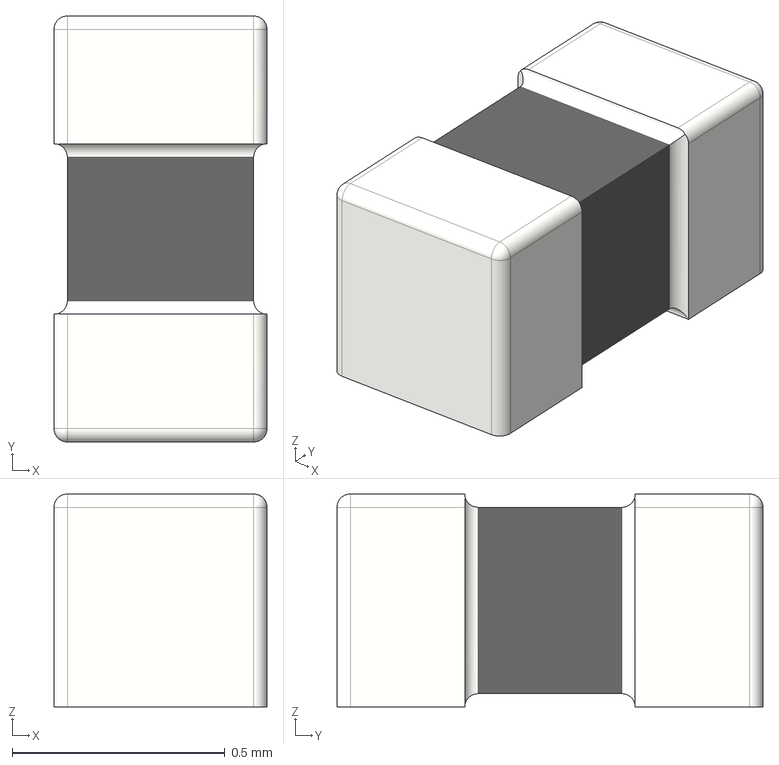
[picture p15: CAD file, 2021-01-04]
pcb/components/passives/L-0402.stp
0.5 x 1.00 x 0.5 mm

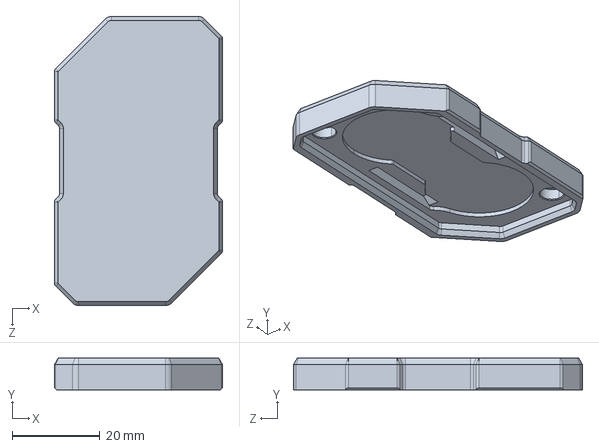
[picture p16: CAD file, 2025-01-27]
case/caseTop.STEP
38.4 x 7.30 x 66.0 mm

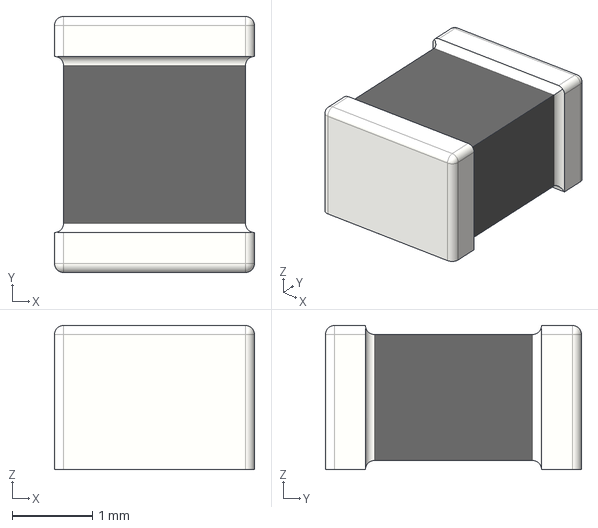
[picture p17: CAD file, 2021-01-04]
pcb/components/passives/L-1210.stp
2.50 x 3.20 x 1.80 mm

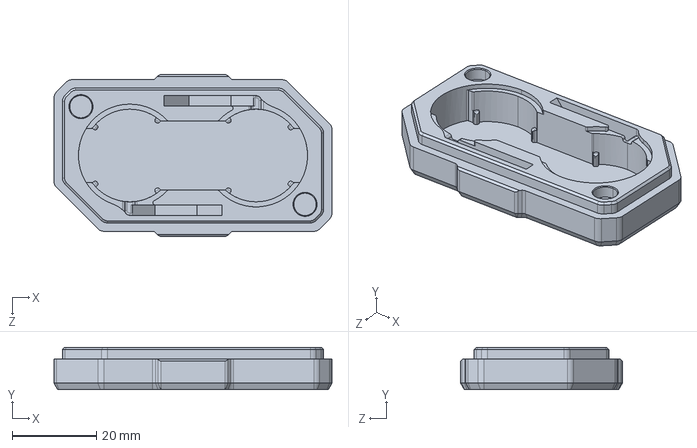
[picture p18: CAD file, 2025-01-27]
case/caseBot.STEP
66.0 x 10.0 x 38.4 mm

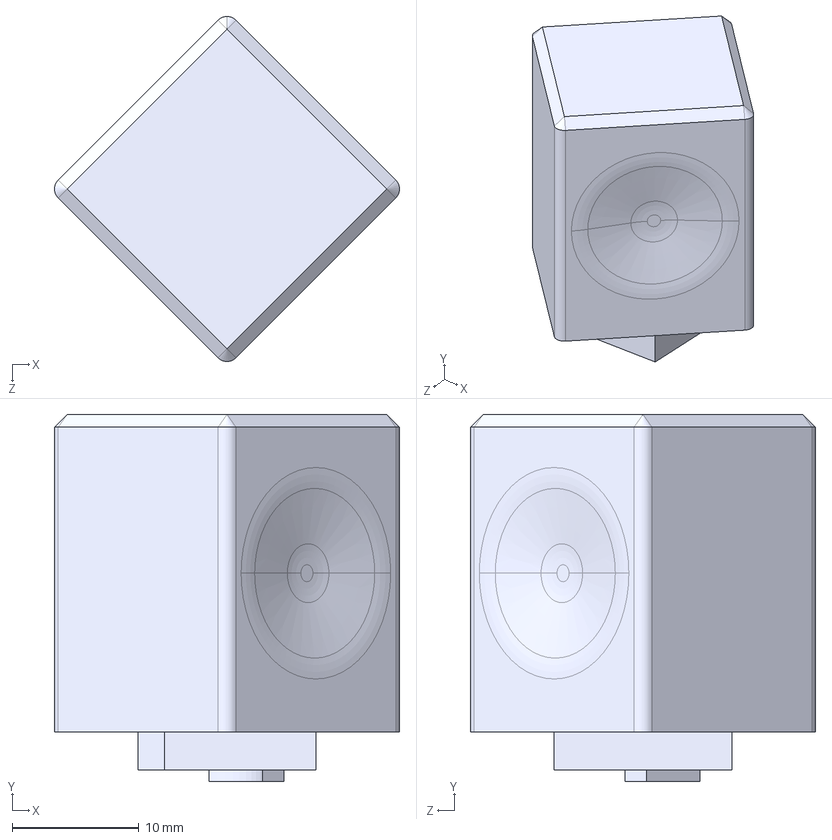
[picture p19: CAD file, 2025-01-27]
case/magnetJig.STEP
27.2 x 28.9 x 27.2 mm

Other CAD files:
pcb/components/passives/C-1210.stp
pcb/components/passives/L-0805.stp
pcb/components/passives/C-0201.stp
pcb/components/passives/R-0603.stp
case/caseTop.STL
case/magnetJig.STL
pcb/components/passives/C-0402.stp
pcb/components/passives/C-0603.stp
pcb/components/passives/C-0805.stp
pcb/components/passives/C-1206.stp
pcb/components/passives/C-1812.stp
pcb/components/passives/C-2220.stp
pcb/components/passives/L-0603.stp
pcb/components/passives/L-1206.stp
pcb/components/passives/R-0402.stp
pcb/components/passives/R-0805.stp
pcb/components/passives/R-1206.stp

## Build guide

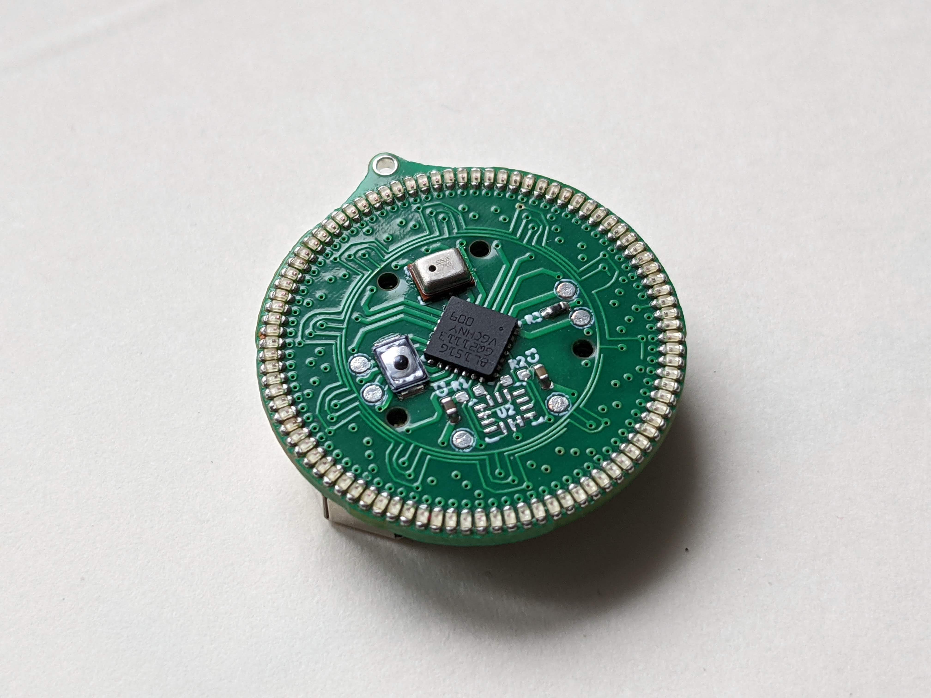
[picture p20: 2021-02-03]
docs/pcbAssembly/front-iso.jpg

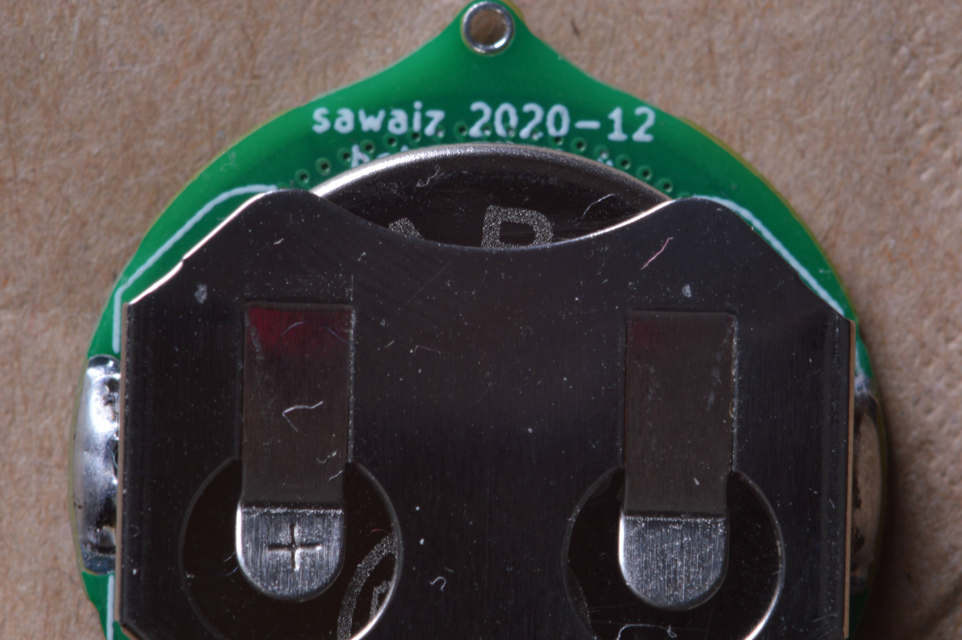
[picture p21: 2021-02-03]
docs/pcbAssembly/back-detail.jpg

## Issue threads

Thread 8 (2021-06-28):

CAD File?

notDave0, 2021-06-28:
Thanks for this project. These are amazing! I'd like to model up and print some clear cases for mine. Do you have a solid model for the populated PCBAs?

sawaiz, 2021-06-28:
Sure, see if this works for you. You can also export directly form KiCad, and I might have IPT files if those would be better, I’m traveling today, so don’t have access to them just yet.

Regards,
Sawaiz

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

notDave0, 2021-08-23:
An .ipt would work well for me. I don't currently run KiCad

Regards,
Dave

sawaiz, 2024-01-15:
Sorry I completely forgot about this. Here is a step and ipt file.

[halo-90.zip](https://github.com/openKolibri/halo-90/files/13942997/halo-90.zip)

Closed 2024-01-15.

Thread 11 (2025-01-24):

Case Source File missing

yonk42, 2025-01-24:
Hey, maybe I missed it, but is the source/CAD file for the 3D printed case available anywhere?

Could you maybe add it to the repository? I would like to slightly adapt mine (I have a thicker PCB).

sawaiz, 2025-01-27:
Hey, added in [/case](https://github.com/openKolibri/halo-90/tree/master/case). Step and STL files. There are some new files being designed for housings but better to just upload what I have now. There is also magnet installation tools. Magents used are inexpensive 5mm x 3mm N42 or N45 (N52 ones were way too strong).

Closed 2025-01-27.

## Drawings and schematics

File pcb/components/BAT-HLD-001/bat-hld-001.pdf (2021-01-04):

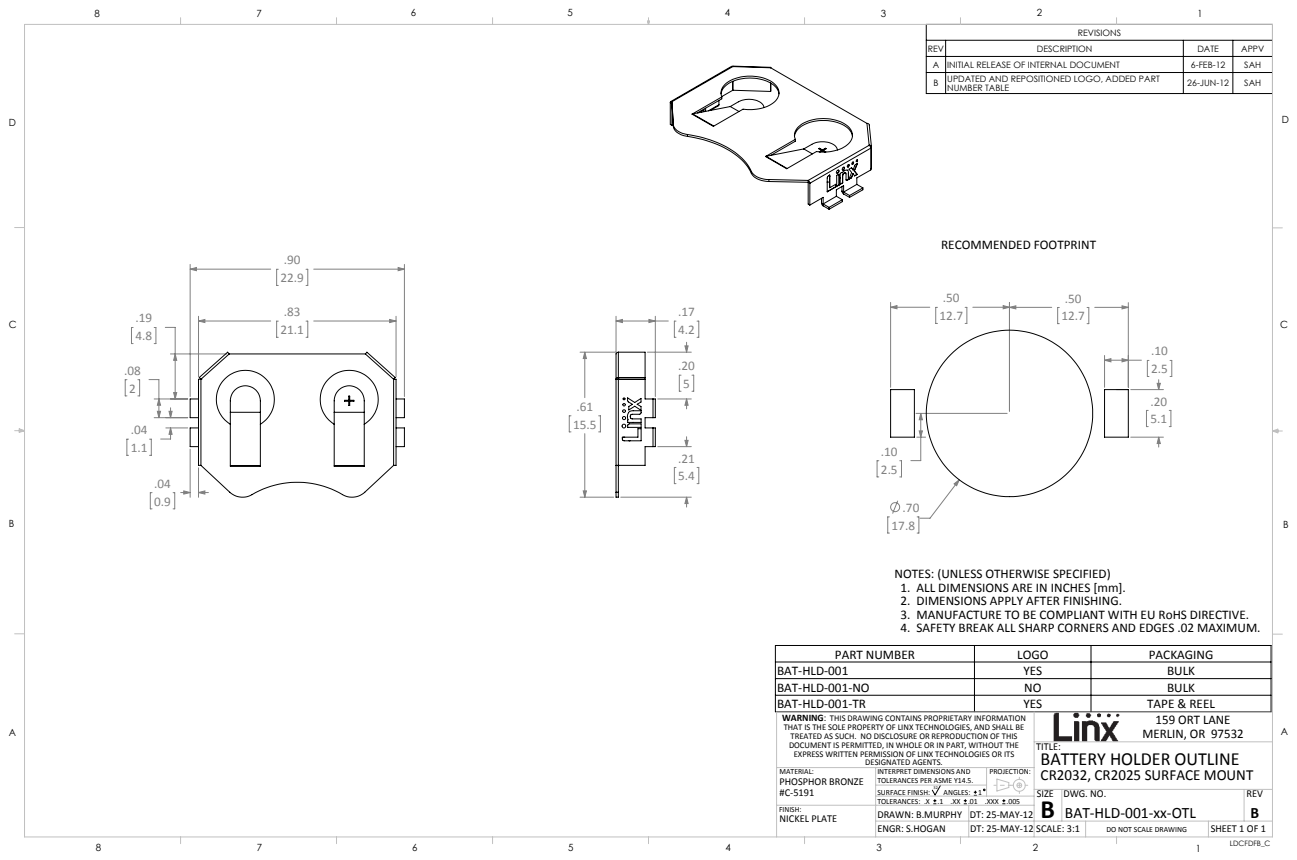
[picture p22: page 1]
RECOMMENDED FOOTPRINT; DT: 25-MAY-12; SURFACE FINISH:; ANGLES:; 159 ORT LANE MERLIN, OR 97532; SIZE DWG. NO.; REV; SHEET 1 OF 1

REV | UPDATED AND REPOSITIONED LOGO, ADDED PART INITIAL RELEASE OF INTERNAL DOCUMENT DESCRIPTION | 6-FEB-12 DATE | APPV A SAH B

NUMBER TABLE | 26-JUN-12 | SAH

NOTES: (UNLESS OTHERWISE SPECIFIED)
1. ALL DIMENSIONS ARE IN INCHES [mm].
2. DIMENSIONS APPLY AFTER FINISHING.
3. MANUFACTURE TO BE COMPLIANT WITH EU RoHS DIRECTIVE.
4. SAFETY BREAK ALL SHARP CORNERS AND EDGES .02 MAXIMUM.

PART NUMBER | LOGO | PACKAGING

BAT-HLD-001 | YES | BULK
BAT-HLD-001-NO | NO | BULK
BAT-HLD-001-TR | YES | TAPE & REEL

WARNING: THIS DRAWING CONTAINS PROPRIETARY INFORMATION
THAT IS THE SOLE PROPERTY OF LINX TECHNOLOGIES, AND SHALL BE
TREATED AS SUCH. NO DISCLOSURE OR REPRODUCTION OF THIS
DOCUMENT IS PERMITTED, IN WHOLE OR IN PART, WITHOUT THE
EXPRESS WRITTEN PERMISSION OF LINX TECHNOLOGIES OR ITS
MATERIAL:
PHOSPHOR BRONZE
FINISH:
NICKEL PLATE

TITLE: B
BATTERY HOLDER OUTLINE
CR2032, CR2025 SURFACE MOUNT
BAT-HLD-001-xx-OTL
SCALE: 3:1

DESIGNATED AGENTS.
INTERPRET DIMENSIONS AND
TOLERANCES PER ASME Y14.5.
TOLERANCES: .X .1 .XX .01 .XXX .005
DRAWN: B.MURPHY
ENGR: S.HOGAN

DO NOT SCALE DRAWING

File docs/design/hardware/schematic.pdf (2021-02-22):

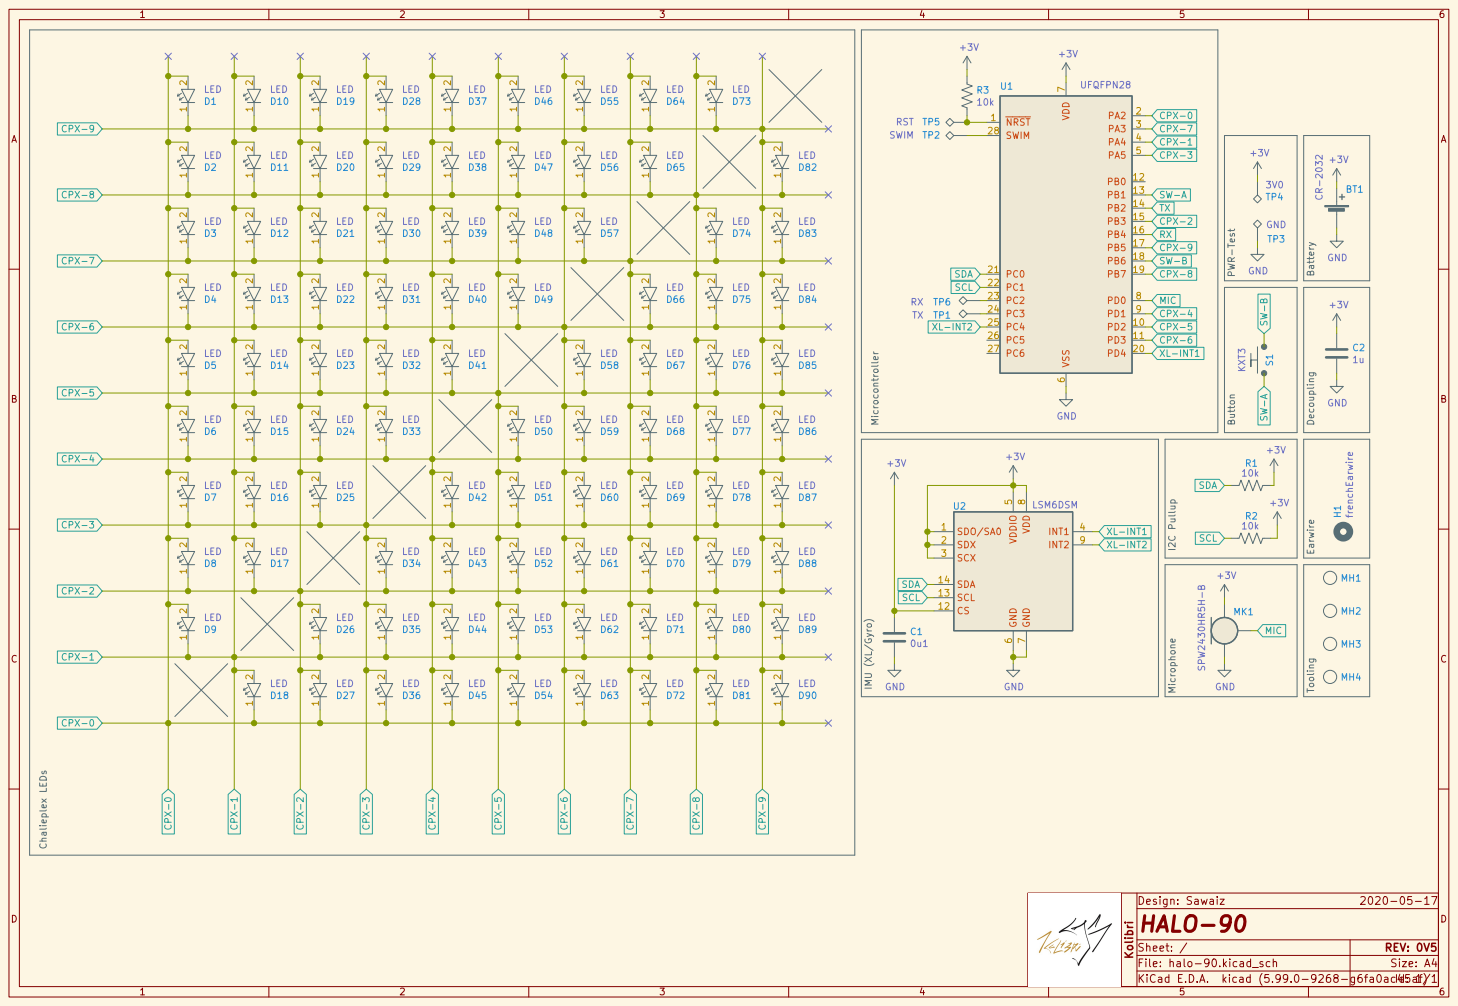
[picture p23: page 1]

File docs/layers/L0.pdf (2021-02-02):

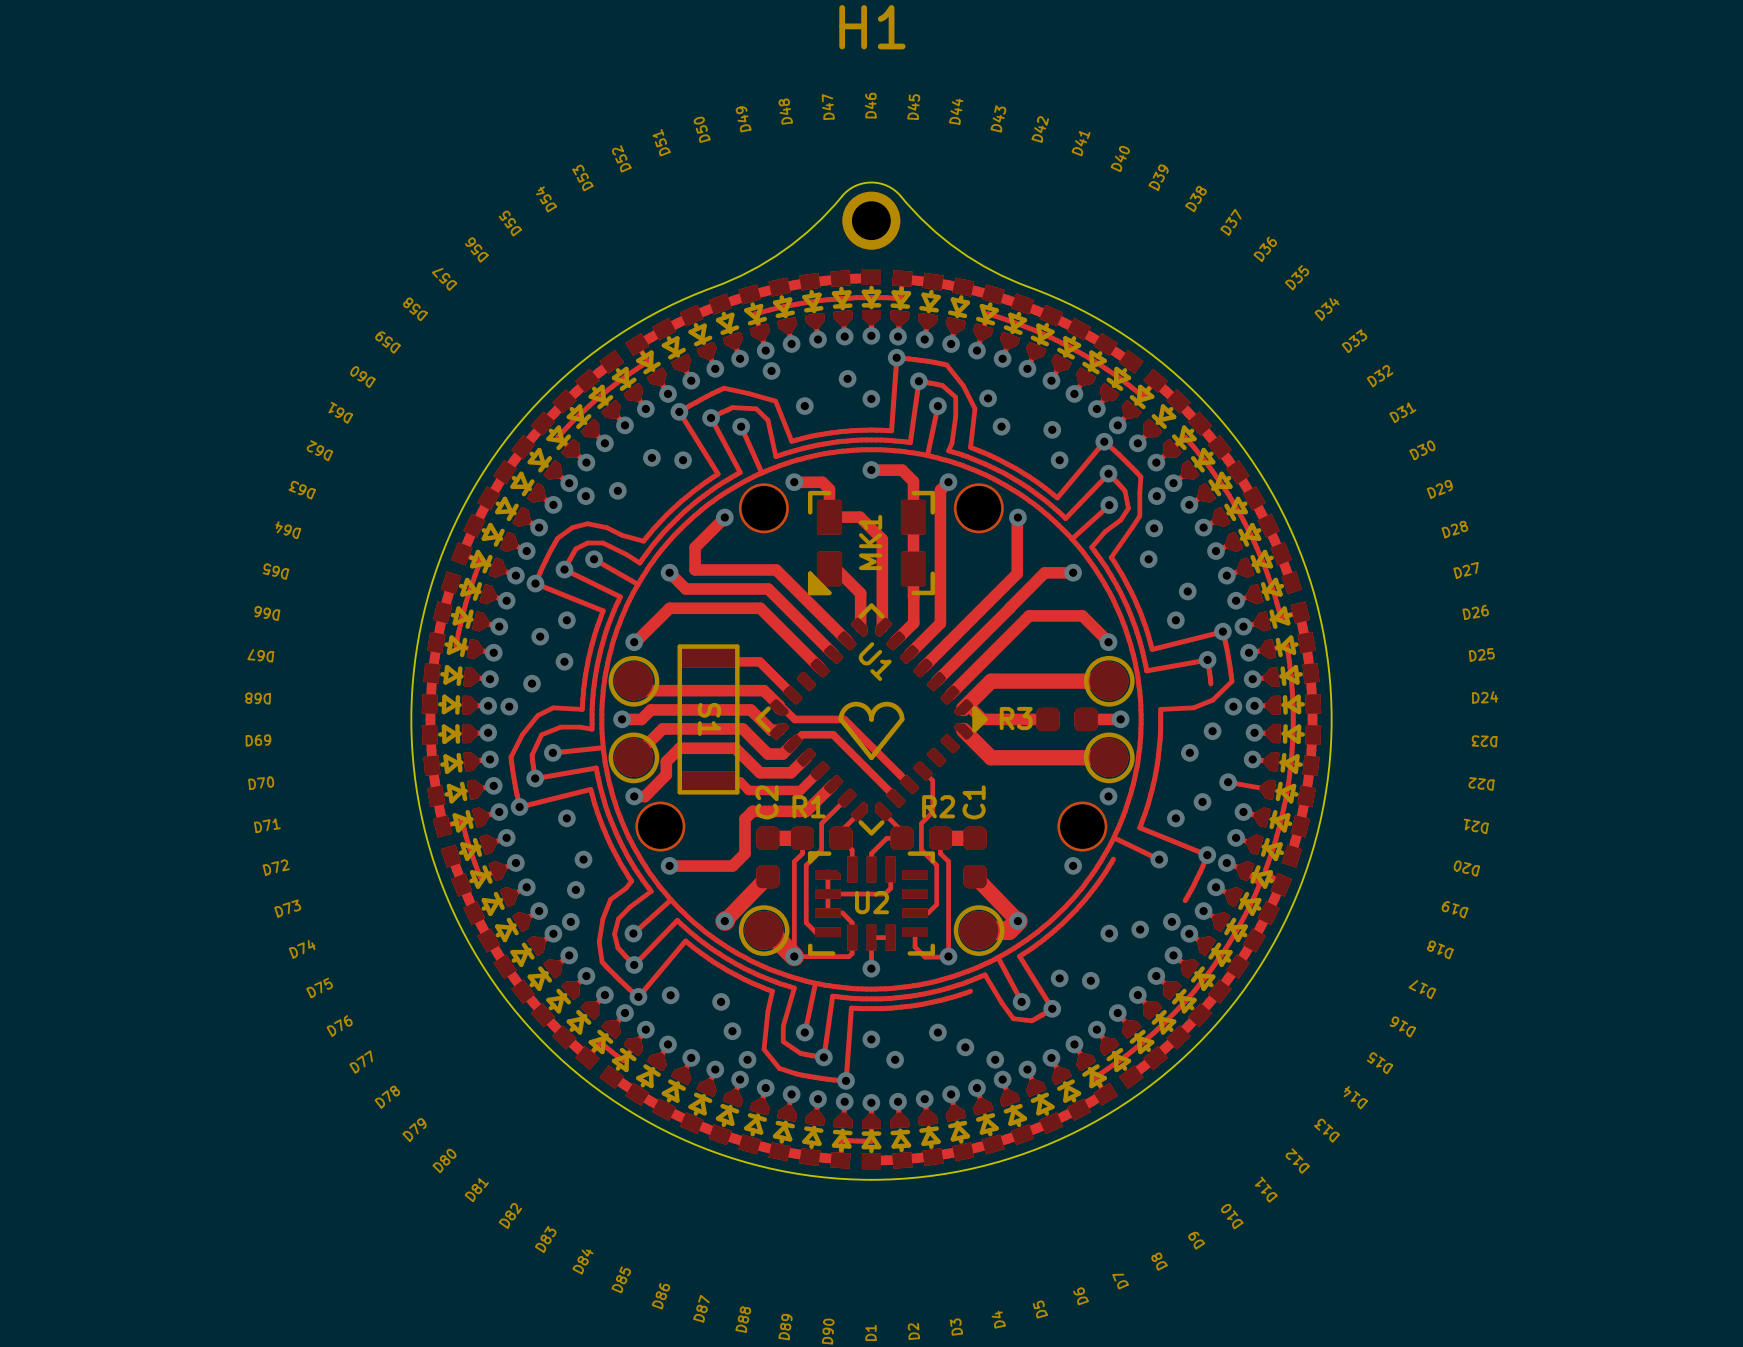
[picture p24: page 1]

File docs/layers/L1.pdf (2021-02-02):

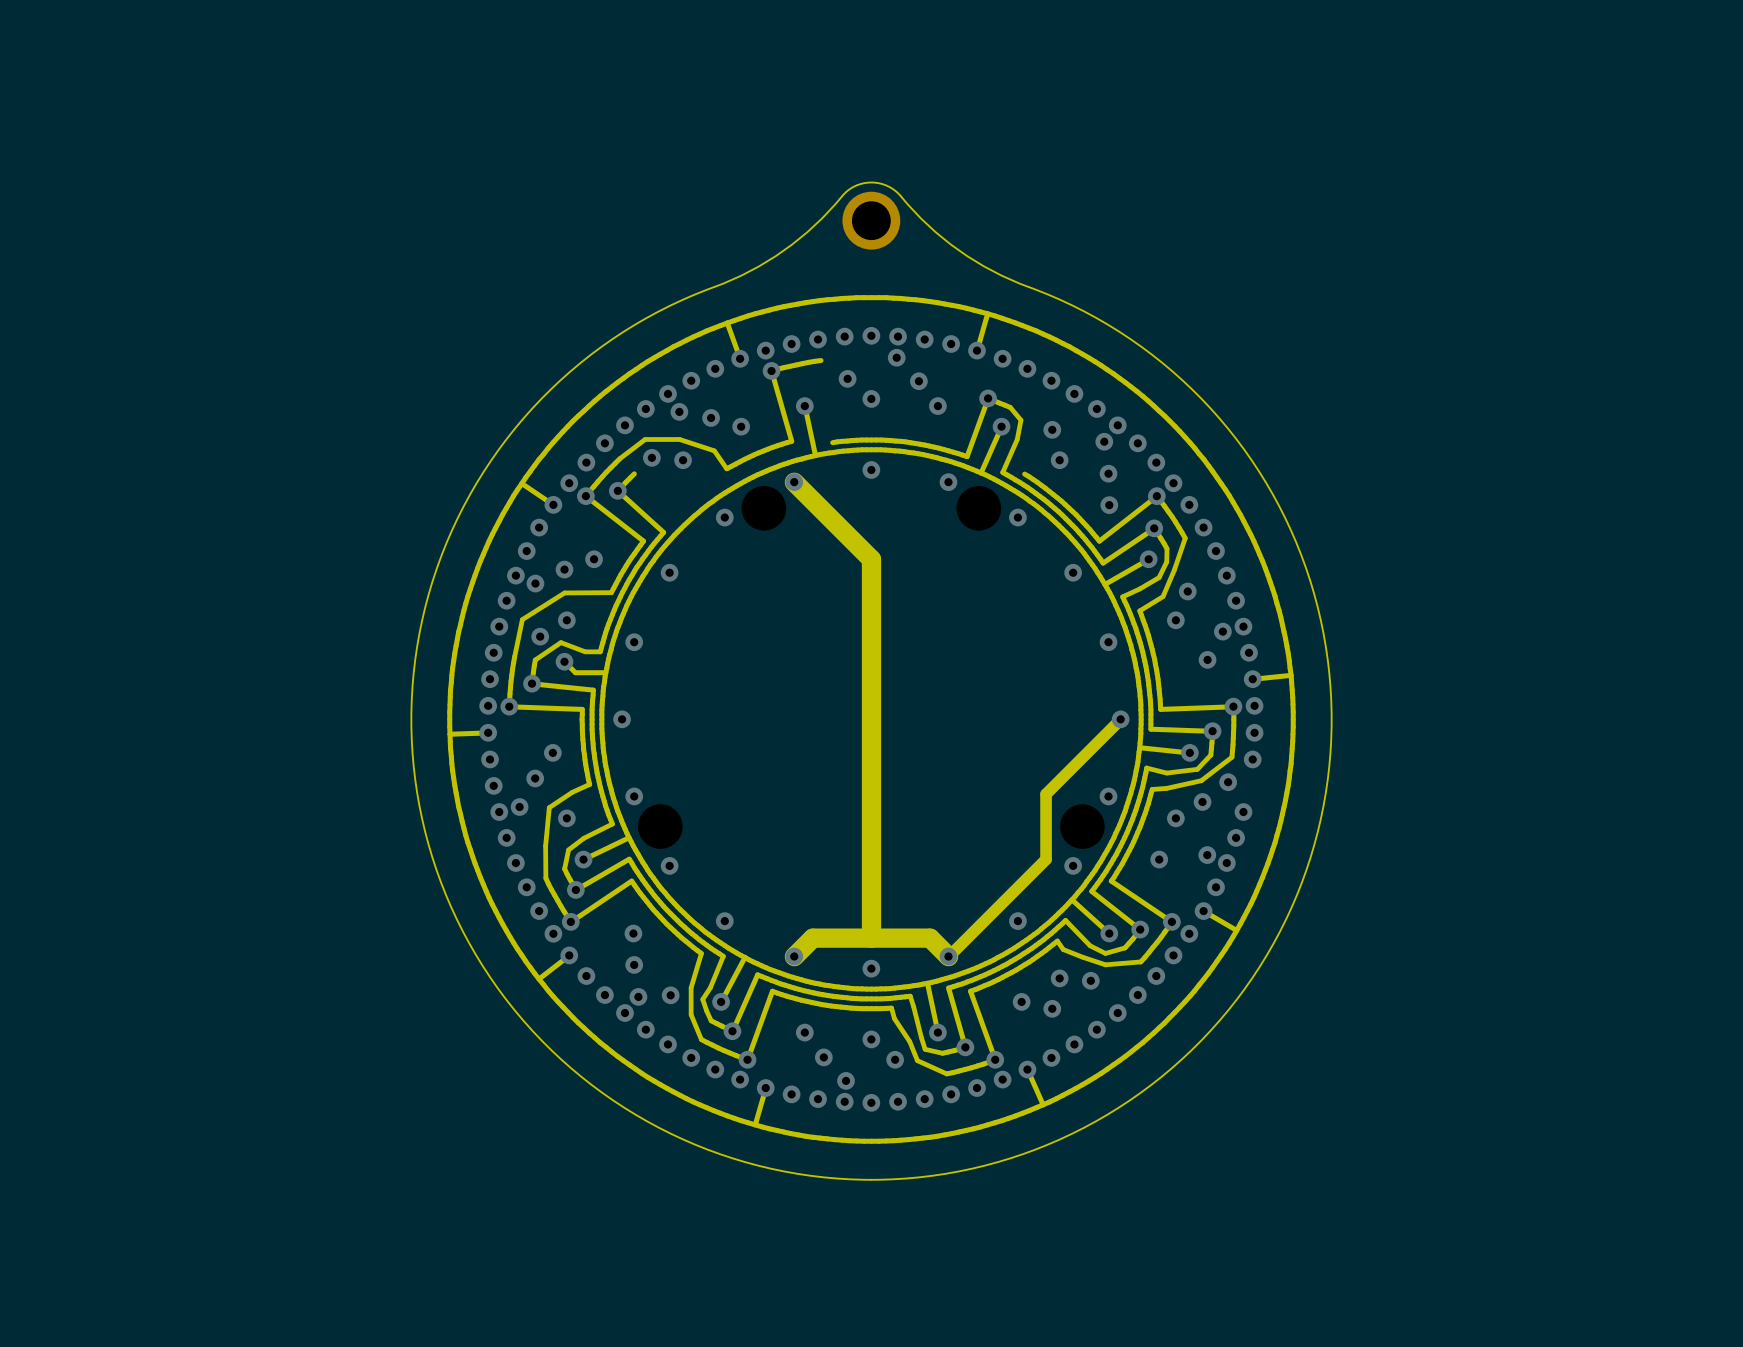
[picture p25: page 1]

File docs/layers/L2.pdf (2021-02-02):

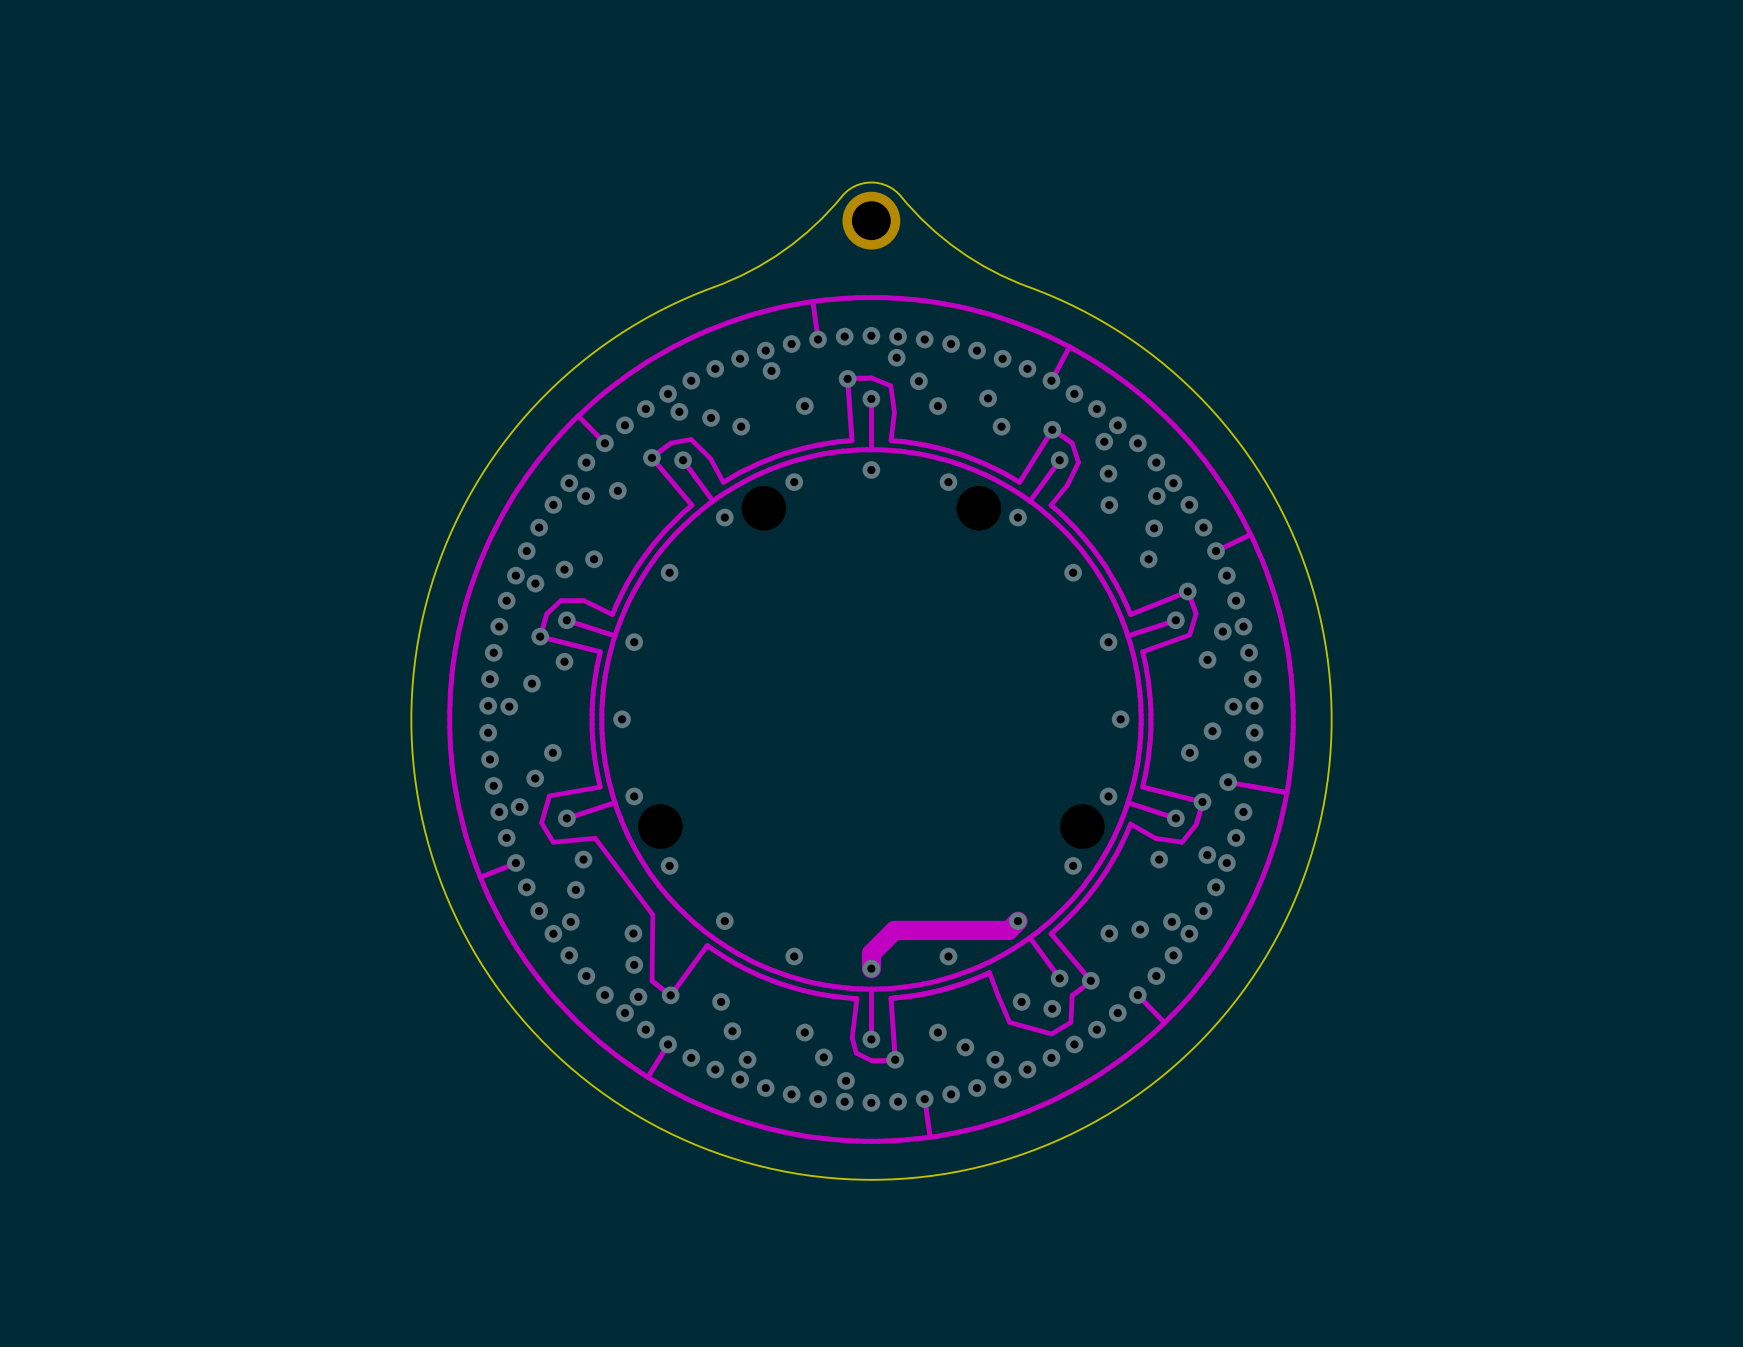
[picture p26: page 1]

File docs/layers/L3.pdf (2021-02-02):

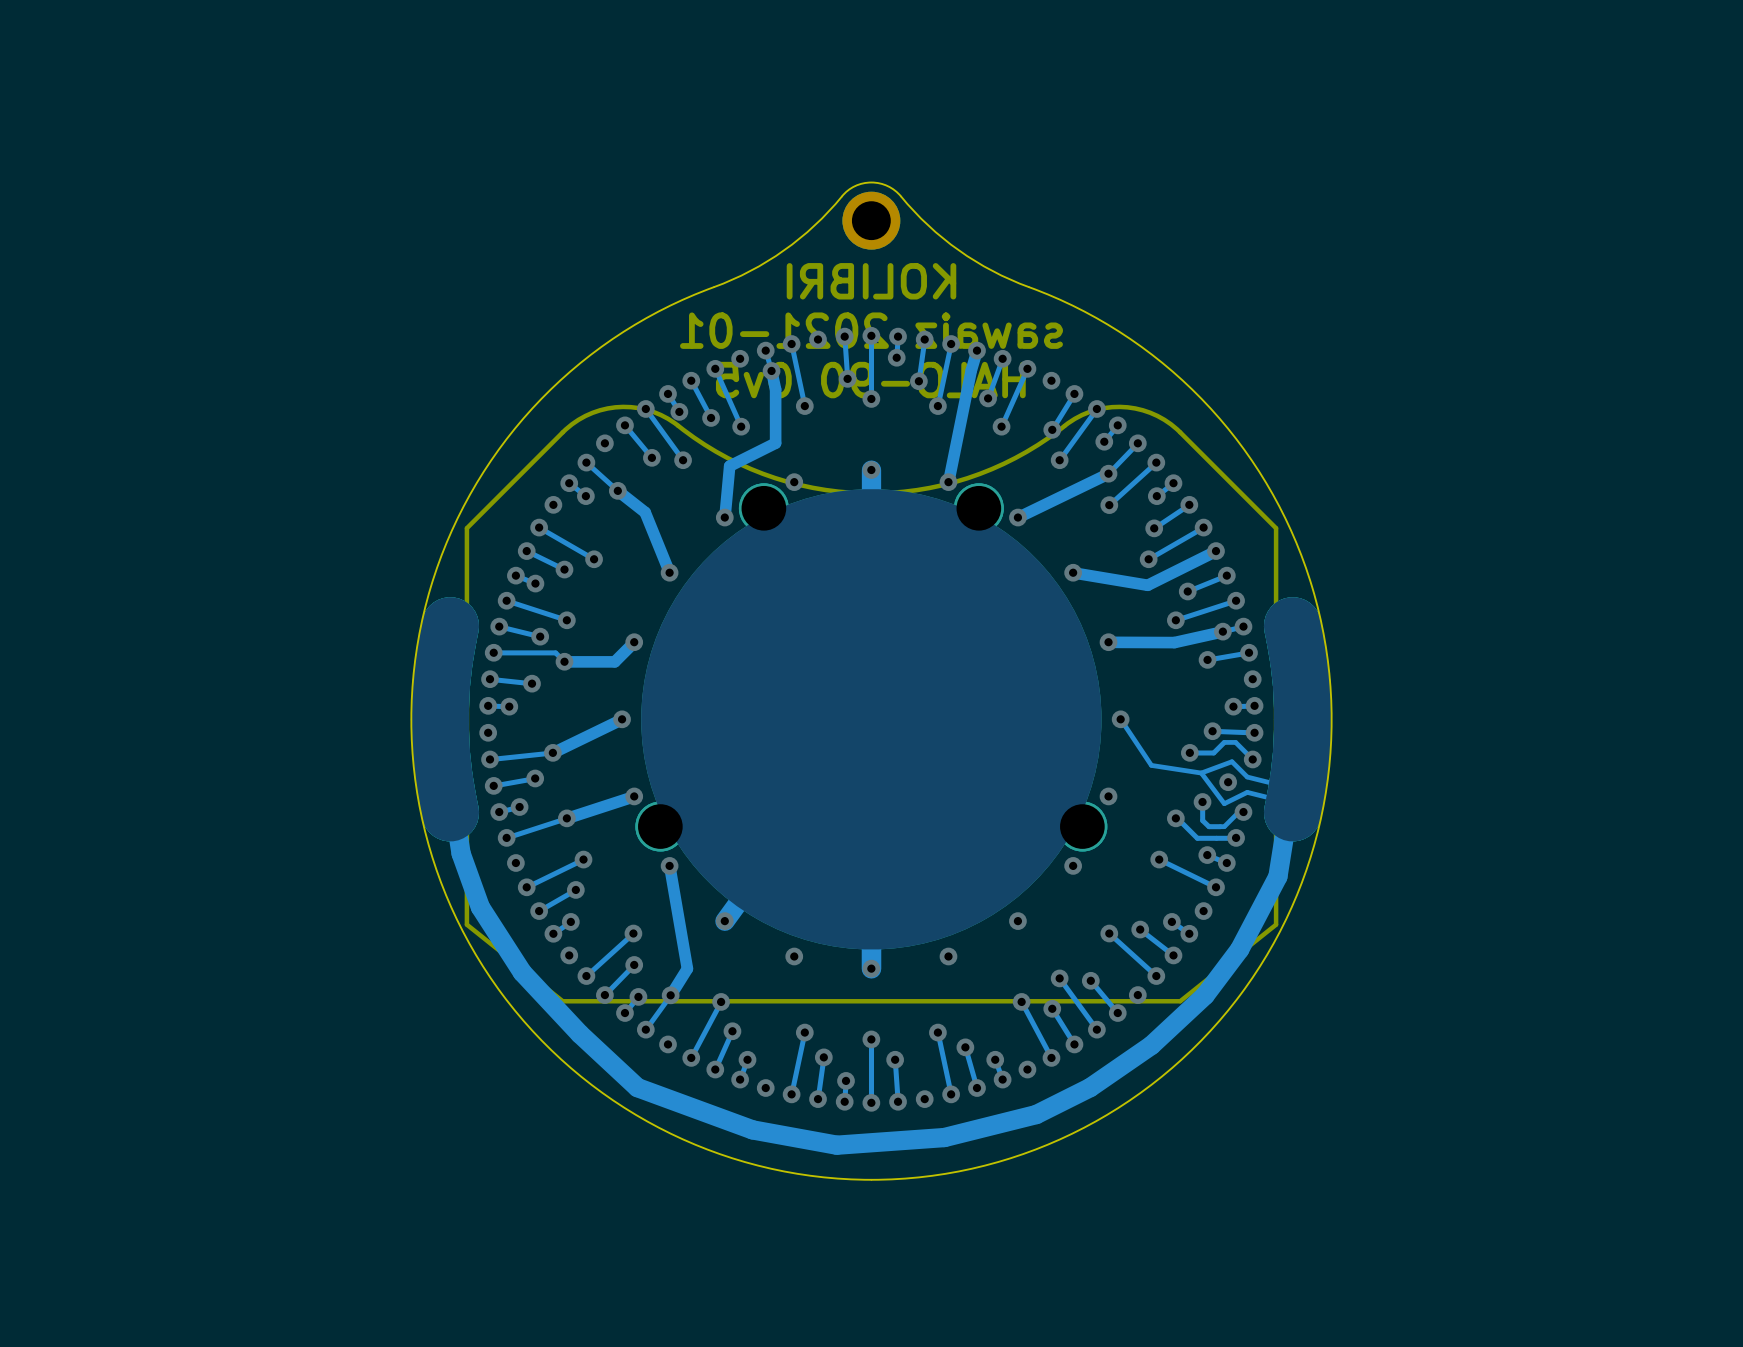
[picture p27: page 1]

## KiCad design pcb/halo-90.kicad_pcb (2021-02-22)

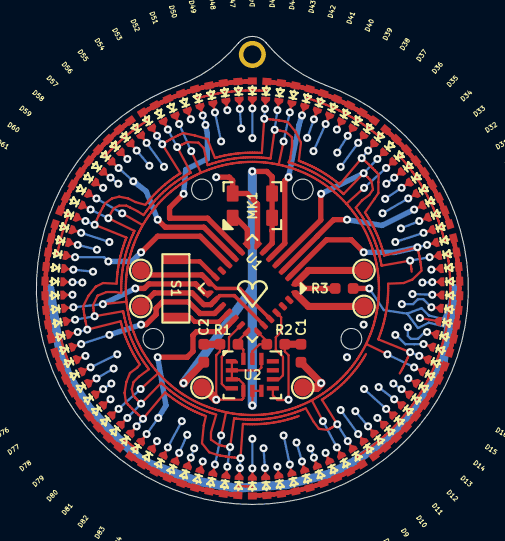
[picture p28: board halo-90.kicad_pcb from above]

Board: 4 copper layers, 24.0 x 26.0 mm, 111 parts (1 on the bottom side), 23 nets.

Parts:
BT1: CR-2032; BAT-HLD-001-HALO
C1: 0u1; C-0402
C2: 1u; C-0402
D1, D2, D3, D4, D5, D6, D7, D8, D9, D10, D11, D12, D13, D14, D15, D16, D17, D18, D19, D20, D21, D22, D23, D24, D25, D26, D27, D28, D29, D30, D31, D32, D33, D34, D35, D36, D37, D38, D39, D40, D41, D42, D43, D44, D45, D46, D47, D48, D49, D50, D51, D52, D53, D54, D55, D56, D57, D58, D59, D60, D61, D62, D63, D64, D65, D66, D67, D68, D69, D70, D71, D72, D73, D74, D75, D76, D77, D78, D79, D80, D81, D82, D83, D84, D85, D86, D87, D88, D89, D90: LED; D-0402
H1: frenchEarwire; earringHookWire
MH1, MH2, MH3, MH4: toolingHole; 1.152mm-ToolingHole
MK1: SPW2430HR5H-B
R1, R2, R3: 10k; R-0402
S1: KXT3
TP1: TX; TestPoint_Pad_D1.0mm
TP2: SWIM; TestPoint_Pad_D1.0mm
TP3: GND; TestPoint_Pad_D1.0mm
TP4: 3V0; TestPoint_Pad_D1.0mm
TP5: RST; TestPoint_Pad_D1.0mm
TP6: RX; TestPoint_Pad_D1.0mm
U1: UFQFPN28
U2: LSM6DSM; LGA-14_3x2.5mm_6-6

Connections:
+3V: BT1.1 (+), C1.1, C2.1, MK1.4 (VDD), R1.2, R2.2, R3.1, TP4.1, U1.7 (VDD), U2.1 (SDO/SA0), U2.2 (SDX), U2.3 (SCX), U2.5 (VDDIO), U2.8 (VDD), U2.12 (CS)
CPX-0: D1.2 (K), D2.2 (K), D3.2 (K), D4.2 (K), D5.2 (K), D6.2 (K), D7.2 (K), D8.2 (K), D9.2 (K), D18.1 (A), D27.1 (A), D36.1 (A), D45.1 (A), D54.1 (A), D63.1 (A), D72.1 (A), D81.1 (A), D90.1 (A), U1.2 (PA2)
CPX-1: D9.1 (A), D10.2 (K), D11.2 (K), D12.2 (K), D13.2 (K), D14.2 (K), D15.2 (K), D16.2 (K), D17.2 (K), D18.2 (K), D26.1 (A), D35.1 (A), D44.1 (A), D53.1 (A), D62.1 (A), D71.1 (A), D80.1 (A), D89.1 (A), U1.4 (PA4)
CPX-2: D8.1 (A), D17.1 (A), D19.2 (K), D20.2 (K), D21.2 (K), D22.2 (K), D23.2 (K), D24.2 (K), D25.2 (K), D26.2 (K), D27.2 (K), D34.1 (A), D43.1 (A), D52.1 (A), D61.1 (A), D70.1 (A), D79.1 (A), D88.1 (A), U1.15 (PB3)
CPX-3: D7.1 (A), D16.1 (A), D25.1 (A), D28.2 (K), D29.2 (K), D30.2 (K), D31.2 (K), D32.2 (K), D33.2 (K), D34.2 (K), D35.2 (K), D36.2 (K), D42.1 (A), D51.1 (A), D60.1 (A), D69.1 (A), D78.1 (A), D87.1 (A), U1.5 (PA5)
CPX-4: D6.1 (A), D15.1 (A), D24.1 (A), D33.1 (A), D37.2 (K), D38.2 (K), D39.2 (K), D40.2 (K), D41.2 (K), D42.2 (K), D43.2 (K), D44.2 (K), D45.2 (K), D50.1 (A), D59.1 (A), D68.1 (A), D77.1 (A), D86.1 (A), U1.9 (PD1)
CPX-5: D5.1 (A), D14.1 (A), D23.1 (A), D32.1 (A), D41.1 (A), D46.2 (K), D47.2 (K), D48.2 (K), D49.2 (K), D50.2 (K), D51.2 (K), D52.2 (K), D53.2 (K), D54.2 (K), D58.1 (A), D67.1 (A), D76.1 (A), D85.1 (A), U1.10 (PD2)
CPX-6: D4.1 (A), D13.1 (A), D22.1 (A), D31.1 (A), D40.1 (A), D49.1 (A), D55.2 (K), D56.2 (K), D57.2 (K), D58.2 (K), D59.2 (K), D60.2 (K), D61.2 (K), D62.2 (K), D63.2 (K), D66.1 (A), D75.1 (A), D84.1 (A), U1.11 (PD3)
CPX-7: D3.1 (A), D12.1 (A), D21.1 (A), D30.1 (A), D39.1 (A), D48.1 (A), D57.1 (A), D64.2 (K), D65.2 (K), D66.2 (K), D67.2 (K), D68.2 (K), D69.2 (K), D70.2 (K), D71.2 (K), D72.2 (K), D74.1 (A), D83.1 (A), U1.3 (PA3)
CPX-8: D2.1 (A), D11.1 (A), D20.1 (A), D29.1 (A), D38.1 (A), D47.1 (A), D56.1 (A), D65.1 (A), D73.2 (K), D74.2 (K), D75.2 (K), D76.2 (K), D77.2 (K), D78.2 (K), D79.2 (K), D80.2 (K), D81.2 (K), D82.1 (A), U1.19 (PB7)
CPX-9: D1.1 (A), D10.1 (A), D19.1 (A), D28.1 (A), D37.1 (A), D46.1 (A), D55.1 (A), D64.1 (A), D73.1 (A), D82.2 (K), D83.2 (K), D84.2 (K), D85.2 (K), D86.2 (K), D87.2 (K), D88.2 (K), D89.2 (K), D90.2 (K), U1.17 (PB5)
GND: BT1.2 (-), C1.2, C2.2, MK1.2 (GND), MK1.3 (GND), TP3.1, U2.6 (GND), U2.7 (GND)
MIC: MK1.1 (Output), U1.8 (PD0)
unnamed: R3.2, TP5.1, U1.1 (~NRST)
unnamed: TP2.1, U1.28 (SWIM)
RX: TP6.1, U1.16 (PB4), U1.23 (PC2)
SCL: R2.1, U1.22 (PC1), U2.13 (SCL)
SDA: R1.1, U1.21 (PC0), U2.14 (SDA)
SW-A: S1.1, U1.13 (PB1)
SW-B: S1.2, U1.18 (PB6)
TX: TP1.1, U1.14 (PB2), U1.24 (PC3)
XL-INT1: U1.20 (PD4), U2.4 (INT1)
XL-INT2: U1.25 (PC4), U2.9 (INT2)

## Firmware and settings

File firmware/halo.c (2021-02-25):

// halo.c halo control and procesing
// Copyright (C) 2021 Kolibri - Sawaiz Syed

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
#include <stdio.h>
#include <stdlib.h>
#include <string.h>
#include <math.h>

// #define __SDCC
#include "STM8L151G6.h"

// Prototypes
uint16_t readMic();
void setLed(uint8_t led);
void ledHigh(uint8_t led);
void ledLow(uint8_t led);

void initADC();
void enableADC();
void disableADC();
void initButton();
void enableButton();
void disableButton();
void initTim2(uint16_t timeout);
void enableTim2();
void disableTim2();
void initTim4(uint8_t timeout);
void enableTim4();
void disableTim4();
void initAutoWakeup();
void enableAutoWakeup(uint16_t timeout);
void disableAutoWakeup();

// Global previousLed
volatile uint8_t prevLed = 0;
int8_t rotationCenter = 45;
int8_t rotDir = 1;
volatile uint8_t patternNum = 0;
volatile uint8_t sleep = 0;

// CPX-0, PA2
// CPX-1, PA4
// CPX-2, PB3
// CPX-3, PA5
// CPX-4, PD1
// CPX-5, PD2
// CPX-6, PD3
// CPX-7, PA3
// CPX-8, PB7
// CPX-9, PB5
PORT_t *CPX_PORT[] = {&sfr_PORTA, &sfr_PORTA, &sfr_PORTB, &sfr_PORTA,
                      &sfr_PORTD, &sfr_PORTD, &sfr_PORTD, &sfr_PORTA,
                      &sfr_PORTB, &sfr_PORTB};
uint8_t CPX_PIN[] = {PIN2, PIN4, PIN3, PIN5, PIN1,
                     PIN2, PIN3, PIN3, PIN7, PIN5};

PORT_t *SW_PORT[] = {&sfr_PORTB, &sfr_PORTB};
uint8_t SW_PIN[] = {PIN1, PIN6};


ISR_HANDLER(RTC_WAKEUP, _RTC_WAKEUP_VECTOR_) {
  switch(patternNum){
    case 1:
      // Halo
      setLed((prevLed + 13)%90);
    break;

    case 2:
      // Sparkle
      rand()%15 ? ledLow(prevLed) : setLed(rand() % 90);
    break;

    default:
    break;
  }
  sfr_RTC.ISR2.WUTF = 0;     // Reset wakeup flag
  return;
}

ISR_HANDLER(TIM2_UPD_ISR, _TIM2_OVR_UIF_VECTOR_) {
  rotationCenter = (rotationCenter+rotDir)%90;
  sfr_TIM2.SR1.UIF = 0;  // clear timer 2 interrupt flag
  return;
}

// ADC end of conversion interupt
ISR_HANDLER(ADC1_EOC_ISR, _ADC1_EOC_VECTOR_){
  // Raw waveform
  sfr_ADC1.CR1.ADON = 0;        // Turn off ADC
  uint16_t adc = sfr_ADC1.DRL.byte | ((uint16_t)sfr_ADC1.DRH.byte)<<8;
  // Calculate the LED angle/4 0-89
  setLed((uint8_t)((4140 + rotationCenter + adc) % 90));
  sfr_ADC1.SR.EOC = 0 ;    // Clear EOC bit
  
  sfr_ADC1.CR1.ADON = 1;        // Enable ADC
  sfr_ADC1.SQR2.CHSEL_S22 = 1;  // ADC to D0, ADC1_IN22
  for(int i = 0; i < 48; i++){} // Delay t_wakeup, 3us 48 cycles
  sfr_ADC1.CR1.START = 1;       // Start Conversion
  return;
}

// Button ISR
ISR_HANDLER(BUTTON_ISR, _EXTI6_VECTOR_){
  // Button release debounce
  for(uint16_t i = 0 ; i < 5000; i++){NOP();}
  if(!(SW_PORT[1]->IDR.byte & SW_PIN[1])){
    if(!sleep){
      initTim4(244);
      enableTim4();                      // Start timer
      patternNum = (patternNum+1)%3;     //   Next pattern
      switch(patternNum){
        case 0:
          sfr_CPU.CFG_GCR.AL = 0; // Enable main WFI loop
          disableAutoWakeup();
          enableADC();
          enableTim2();
        break;
        case 1:
          disableTim2();         // Turn off timer
          disableADC();          // Turn off ADC
          sfr_CPU.CFG_GCR.AL = 1;// Interupt only based, IRET to HALT
          enableAutoWakeup(2);
        break;
        case 2:
          disableADC();          // Turn off ADC
          disableTim2();         // Turn off timer
          sfr_CPU.CFG_GCR.AL = 1;// Interupt only based, IRET to HALT
          enableAutoWakeup(100);
        break;
      }
    } else {
      // I hate this so much, it is so inefficent
      // Should be implemented as the same TIM4 timeout
      // At least it lets me debounce better
      // And a boot animation
      uint16_t debounce = 0; 
      for(uint16_t i = 0 ; i < 20000; i++){
        if(!(SW_PORT[1]->IDR.byte & SW_PIN[1])){
          debounce++;
          setLed(debounce/200); 
        }
        if(debounce > 18000){SW_RESET();}
      }
      ledLow(prevLed);
    }
  }
  sfr_ITC_EXTI.SR1.P6F = 1; // Clear button interupt flag
  return;
}

// Button has been held for timeout period
ISR_HANDLER(TIM4_UPD_ISR, _TIM4_UIF_VECTOR_) {
  ledLow(prevLed);
  // If button is still down
  if(!(SW_PORT[1]->IDR.byte & SW_PIN[1])){
    if(!sleep){ 
      sfr_CPU.CFG_GCR.AL = 1;// Interupt only based, IRET to HALT
      disableTim2();         // Turn off timer
      disableADC();          // Turn off ADC
      disableTim4();
      disableAutoWakeup();
      sfr_TIM4.SR1.UIF = 0;  // clear timer 4 interrupt flag
      sleep = 1;
      ledLow(prevLed);       // All LEDs off
      ENTER_HALT();          // Low power mode
      return;
    }
  }
  sfr_TIM4.SR1.UIF = 0;  // clear timer 4 interrupt flag
  return;
}

void main() {
  DISABLE_INTERRUPTS();

  // Bump up clock to 16MHz
  sfr_CLK.CKDIVR.byte = 0x00;

  // Init and Set all CPX pins to hi-z
  for (int k = 0; k < sizeof(CPX_PIN) / sizeof(CPX_PIN[0]); k++) {
    CPX_PORT[k]->DDR.byte &= ~CPX_PIN[k];
    CPX_PORT[k]->CR1.byte &= ~CPX_PIN[k];
  }

  initADC();
  initTim2(5000);
  initButton();
  initAutoWakeup();

  disableAutoWakeup();
  enableADC();
  enableTim2();

  ENABLE_INTERRUPTS();

  while(1){
    WAIT_FOR_INTERRUPT();
  }
}

uint16_t readMic() {
  sfr_ADC1.CR1.ADON = 1;        // Enable ADC
  sfr_ADC1.SQR2.CHSEL_S22 = 1;  // ADC to D0, ADC1_IN22
  for(int i = 0; i < 12; i++){} // Delay t_wakeup, 3us 48 cycles
  sfr_ADC1.CR1.START = 1;       // Start Conversion
  while (!sfr_ADC1.SR.EOC);     // conversion ready
  sfr_ADC1.CR1.ADON = 0;        // Turn off ADC
  return sfr_ADC1.DRL.byte | ((uint16_t)sfr_ADC1.DRH.byte)<<8;
}

void initTim2(uint16_t timeout){
  sfr_CLK.PCKENR1.PCKEN10 = 1;                   // activate tim2 clock gate
  sfr_TIM2.CR1.CEN = 0;                          // disable timer
  sfr_ITC_SPR.SPR5.VECT19SPR = 0b01;             // Interupt Priority to Level 1 (lower)
  sfr_TIM2.CR1.ARPE = 1;                         // auto-reload value buffered
  sfr_TIM2.CNTRH.byte = 0x00;                    // MSB clear counter
  sfr_TIM2.CNTRL.byte = 0x00;                    // LSB clear counter
  sfr_TIM2.EGR.byte = 0x00;                      // clear pending events
  sfr_TIM2.PSCR.PSC = 7;                         // set clock to 16Mhz/2^7 = 125khz -> 8us period
  sfr_TIM2.ARRH.byte = (uint8_t)(timeout >> 8);  // set autoreload value for 50.176ms (=49*1.024ms)
  sfr_TIM2.ARRL.byte = (uint8_t)timeout;         // set autoreload value for 50.176ms (=49*1.024ms)
  sfr_TIM2.IER.UIE = 1;                          // enable timer 4 interrupt
  enableTim2();
}

void enableTim2(){
  sfr_CLK.PCKENR1.PCKEN10 = 1;  // activate tim4 clock gate
  sfr_TIM2.CNTRH.byte = 0x00;   // MSB clear counter
  sfr_TIM2.CNTRL.byte = 0x00;   // LSB clear counter
  sfr_TIM2.IER.UIE = 1;         // enable timer 4 interrupt
  sfr_TIM2.CR1.CEN = 1;         // start the timer
}

void disableTim2(){
  sfr_TIM2.IER.UIE = 0;         // disable interrupt
  sfr_TIM2.CR1.CEN = 0;         // disable timer
  sfr_CLK.PCKENR1.PCKEN10 = 0;  // disable tim4 clock gate
}

void initAutoWakeup(){
  sfr_CLK.CRTCR.RTCSEL1 = 1;                      // Set RTC source to LSI
  while(sfr_CLK.CRTCR.RTCSWBSY){};                // Wait for clock change to finish
  sfr_CLK.PCKENR2.PCKEN22 = 1;                    // Enable RTC Clock gating
  sfr_RTC.WPR.KEY = 0xCA;                         // Disable RTC write protection
  sfr_RTC.WPR.KEY = 0x53;                         // Disable RTC write protection
  sfr_RTC.CR2.WUTE = 0;                           // Disable the wakeup timer
  while(!sfr_RTC.ISR1.WUTWF){}                    // Poll unil bit is written
  sfr_RTC.WUTRH.byte = 0;                         // MSB 16b auto countdown
  sfr_RTC.WUTRL.byte = 1;                         // LSB 16b auto countdown
  sfr_RTC.CR1.WUCKSEL = 3;                        // RTCCLK/2 as wakeup clock
  sfr_CLK.ICKCR.SAHALT = 1;                       // switch off main regulator during halt mode
  sfr_CLK.PCKENR2.PCKEN22 = 0;                    // Disable RTC Clock gating
}

void enableAutoWakeup(uint16_t timeout){
  sfr_CLK.PCKENR2.PCKEN22 = 1;                    // Enable RTC Clock gating
  sfr_ITC_SPR.SPR2.VECT4SPR = 0b00;               // Interupt Priority to Level 2 (mid)
  sfr_RTC.WPR.KEY = 0xCA;                         // Disable RTC write protection
  sfr_RTC.WPR.KEY = 0x53;                         // Disable RTC write protection
  sfr_RTC.CR2.WUTE = 0;                           // Disable the wakeup timer
  while(!sfr_RTC.ISR1.WUTWF){}                    // Poll unil bit is written
  sfr_RTC.WUTRH.byte = (uint8_t)(timeout >> 8);   // MSB 16b auto countdown
  sfr_RTC.WUTRL.byte = (uint8_t)(timeout);        // LSB 16b auto countdown
  sfr_RTC.CR2.WUTIE = 1;                          // Enable wakeup timer interupt
  sfr_RTC.CR2.WUTE = 1;                           // Enable the wakeup timer
}

void disableAutoWakeup(){
  sfr_RTC.WPR.KEY = 0xCA;           // Disable RTC write protection
  sfr_RTC.WPR.KEY = 0x53;           // Disable RTC write protection
  sfr_RTC.CR2.WUTE = 0;             // Disable the wakeup timer
  while(!sfr_RTC.ISR1.WUTWF){}      // Poll unil bit is written
  sfr_RTC.CR2.WUTIE = 0;            // Enable wakeup timer interupt
  sfr_CLK.PCKENR2.PCKEN22 = 0;      // Disable RTC Clock gating
}

void initTim4(uint8_t timeout){
  sfr_CLK.PCKENR1.PCKEN12 = 1;       // activate tim4 clock gate
  sfr_ITC_SPR.SPR7.VECT25SPR = 0b11; // Interupt Priority to Level 3 (max)
  sfr_TIM4.CR1.CEN = 0;              // disable timer
  sfr_TIM4.CNTR.byte = 0x00;         // clear counter
  sfr_TIM4.CR1.ARPE = 1;             // auto-reload value buffered
  sfr_TIM4.CR1.URS = 1;              // Overflow only interupt 
  sfr_TIM4.EGR.byte = 0x00;          // clear pending events
  sfr_TIM4.PSCR.PSC = 15;            // set clock to 16Mhz/2^15 = 488.3Hz -> 2.048ms period
  sfr_TIM4.ARR.byte = timeout;       // set autoreload value for 499.7ms (244*2.048ms)
  sfr_TIM4.CR1.OPM = 1;              // Single pulse mode
  sfr_CLK.PCKENR1.PCKEN12 = 0;       // disable tim4 clock gate
}

void enableTim4(){
  sfr_CLK.PCKENR1.PCKEN12 = 1;  // activate tim4 clock gate
  sfr_TIM4.CNTR.byte = 0x00;    // clear counter
  sfr_TIM4.EGR.UG = 1;          // Generate Update
  sfr_TIM4.IER.UIE = 1;         // enable timer 4 interrupt
  sfr_TIM4.CR1.CEN = 1;         // start the timer
}

void disableTim4(){
  sfr_TIM4.IER.UIE = 0;         // disable interrupt
  sfr_TIM4.CR1.CEN = 0;         // disable timer
  sfr_CLK.PCKENR1.PCKEN12 = 0;  // disable tim4 clock gate
}

void initADC(){
  sfr_ITC_SPR.SPR5.VECT18SPR = 0b01; // ADC Priority to Level 1 (lower)
  sfr_CLK.PCKENR2.PCKEN20 = 1;       // Enable ADC Clock
  sfr_ADC1.CR1.RES = 0b00;           // Set ADC to 12b mode
  sfr_ADC1.CR2.SMTP1 = 0b111;        // Sample time 384
  sfr_ADC1.SQR1.DMAOFF = 1;          // DAMOFF for single ch
  sfr_ADC1.CR1.CONT = 0;             // Disable sampling mode
  // ADC DMA setup
}

void enableADC(){
  sfr_ADC1.CR1.EOCIE = 1;       // Enable EOC Interupt
  // First ADC Conversion
  sfr_ADC1.CR1.ADON = 1;        // Enable ADC
  sfr_ADC1.SQR2.CHSEL_S22 = 1;  // ADC to D0, ADC1_IN22
  for(int i = 0; i < 12; i++){} // Delay t_wakeup, 3us 48 cycles
  sfr_ADC1.CR1.START = 1;       // Start Conversion
}

void disableADC(){
  sfr_ADC1.CR1.EOCIE = 0;       // Disable EOC Interupt
  sfr_ADC1.CR1.ADON = 0;        // Disable ADC
  // sfr_CLK.PCKENR2.PCKEN20 = 0;  // Disable ADC Clock
}

void initButton(){
  // Set switch pins.
  SW_PORT[0]->DDR.byte |= SW_PIN[0];  // DDR = 1 Output
  SW_PORT[0]->CR1.byte |= SW_PIN[0];  // CR1 = 1 Push Pull
  SW_PORT[0]->ODR.byte &= ~SW_PIN[0]; // ODR = 0 Low

  // Pullup with interupt
  SW_PORT[1]->DDR.byte &= ~SW_PIN[1]; // DDR = 0 Input
  SW_PORT[1]->CR1.byte |= SW_PIN[1];  // CR1 = 1 Pullup
  SW_PORT[1]->CR2.byte |= SW_PIN[1];  // CR2 = 1 Interupt
  sfr_ITC_EXTI.CR2.P6IS = 2;          // Falling edge only
}

// The previous LED *MUST* be tuned off before lighting another
// This function automatically takes care of that
void setLed(uint8_t led){
  ledLow(prevLed);
  ledHigh(led);
  prevLed = led;
}

// Enable a specific LED
void ledHigh(uint8_t led) {
  uint8_t col = led / 9;
  uint8_t topElements = 9 - col;
  uint8_t row = 9 - (led % 9);
  if (topElements <= (9 - row)) {
    row--;
  }

  // Set column HIGH
  CPX_PORT[col]->DDR.byte |= CPX_PIN[col];
  CPX_PORT[col]->CR1.byte |= CPX_PIN[col];
  CPX_PORT[col]->ODR.byte |= CPX_PIN[col];
  // Set row LOW
  CPX_PORT[row]->DDR.byte |= CPX_PIN[row];
  CPX_PORT[row]->CR1.byte |= CPX_PIN[row];
  CPX_PORT[row]->ODR.byte &= ~CPX_PIN[row];
}

// Disable a specific LED
void ledLow(uint8_t led) {
  uint8_t col = led / 9;
  uint8_t topElements = 9 - col;
  uint8_t row = 9 - (led % 9);
  if (topElements <= (9 - row)) {
    row--;
  }

  // Set row to HI-Z
  CPX_PORT[row]->ODR.byte |= CPX_PIN[row];
  CPX_PORT[row]->DDR.byte &= ~CPX_PIN[row];
  CPX_PORT[row]->CR1.byte &= ~CPX_PIN[row];
  // Set column to HI-Z
  CPX_PORT[col]->ODR.byte &= ~CPX_PIN[col];
  CPX_PORT[col]->DDR.byte &= ~CPX_PIN[col];
  CPX_PORT[col]->CR1.byte &= ~CPX_PIN[col];
}

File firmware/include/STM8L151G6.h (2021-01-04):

/*-------------------------------------------------------------------------

  STM8L151G6.h - Device Declarations

  Copyright (C) 2020, Georg Icking-Konert

  Ultra-low-power 8-bit MCU with 32 Kbytes Flash, 16 MHz CPU, integrated EEPROM 

  datasheet: https://www.st.com/resource/en/datasheet/stm8l151g6.pdf
  reference: RM0031 https://www.st.com/content/ccc/resource/technical/document/reference_manual/2e/3b/8c/8f/60/af/4b/2c/CD00218714.pdf/files/CD00218714.pdf/jcr:content/translations/en.C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

  MIT License

  Copyright (c) 2020 Georg Icking-Konert

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
-------------------------------------------------------------------------*/

/*-------------------------------------------------------------------------
  MODULE DEFINITION FOR MULTIPLE INCLUSION
-------------------------------------------------------------------------*/
#ifndef STM8L151G6_H
#define STM8L151G6_H

// DEVICE DECLARATION
#define DEVICE  STM8L151G6

// required for C++
#ifdef __cplusplus
  extern "C" {
#endif


/*-------------------------------------------------------------------------
  INCLUDE FILES
-------------------------------------------------------------------------*/
#include <stdint.h>


/*-------------------------------------------------------------------------
  COMPILER SPECIFIC SETTINGS
-------------------------------------------------------------------------*/

// Cosmic compiler
#if defined(__CSMC__)

  // macros to unify ISR declaration and implementation
  #define ISR_HANDLER(func,irq)  @far @interrupt void func(void)      ///< handler for interrupt service routine
  #define ISR_HANDLER_TRAP(func) void @far @interrupt func(void)      ///< handler for trap service routine

  // definition of inline functions
  #define INLINE                 @inline                              ///< keyword for inline functions

  // common assembler instructions
  #define NOP()                  _asm("nop")                          ///< perform a nop() operation (=minimum delay)
  #define DISABLE_INTERRUPTS()   _asm("sim")                          ///< disable interrupt handling
  #define ENABLE_INTERRUPTS()    _asm("rim")                          ///< enable interrupt handling
  #define TRIGGER_TRAP           _asm("trap")                         ///< trigger a trap (=soft interrupt) e.g. for EMC robustness (see AN1015)
  #define WAIT_FOR_INTERRUPT()   _asm("wfi")                          ///< stop code execution and wait for interrupt
  #define ENTER_HALT()           _asm("halt")                         ///< put controller to HALT mode
  #define SW_RESET()             _asm("dc.b $75")                     ///< reset via illegal opcode (works for all devices)

  // data type in bit fields
  #define BITS                   unsigned int                         ///< data type in bit structs (follow C90 standard)


// IAR Compiler
#elif defined(__ICCSTM8__)

  // include intrinsic functions
  #include <intrinsics.h>

  // macros to unify ISR declaration and implementation
  #define STRINGVECTOR(x) #x
  #define VECTOR_ID(x) STRINGVECTOR( vector = (x) )
  #define ISR_HANDLER( a, b )  \
    _Pragma( VECTOR_ID( (b)+2 ) )        \
    __interrupt void (a)( void )
  #define ISR_HANDLER_TRAP(a) \
    _Pragma( VECTOR_ID( 1 ) ) \
    __interrupt void (a) (void)  

  // definition of inline functions
  #define INLINE                 static inline                        ///< keyword for inline functions

  // common assembler instructions
  #define NOP()                  __no_operation()                     ///< perform a nop() operation (=minimum delay)
  #define DISABLE_INTERRUPTS()   __disable_interrupt()                ///< disable interrupt handling
  #define ENABLE_INTERRUPTS()    __enable_interrupt()                 ///< enable interrupt handling
  #define TRIGGER_TRAP           __trap()                             ///< trigger a trap (=soft interrupt) e.g. for EMC robustness (see AN1015)
  #define WAIT_FOR_INTERRUPT()   __wait_for_interrupt()               ///< stop code execution and wait for interrupt
  #define ENTER_HALT()           __halt()                             ///< put controller to HALT mode
  #define SW_RESET()             __asm("dc8 0x75")                    ///< reset via illegal opcode (works for all devices)

  // data type in bit fields
  #define BITS                   unsigned char                        ///< data type in bit structs (deviating from C90 standard)


// SDCC compiler
#elif defined(__SDCC)

  // store SDCC version in preprocessor friendly way
  #define SDCC_VERSION (__SDCC_VERSION_MAJOR * 10000 \
                      + __SDCC_VERSION_MINOR * 100 \
                      + __SDCC_VERSION_PATCH)

  // unify ISR declaration and implementation
  #define ISR_HANDLER(func,irq)   void func(void) __interrupt(irq)    ///< handler for interrupt service routine
  #if SDCC_VERSION >= 30403  // traps require >=v3.4.3
    #define ISR_HANDLER_TRAP(func)  void func() __trap                ///< handler for trap service routine
  #else
    #error traps require SDCC >=3.4.3. Please update!
  #endif

  // definition of inline functions
  #define INLINE                 static inline                        ///< keyword for inline functions

  // common assembler instructions
  #define NOP()                  __asm__("nop")                       ///< perform a nop() operation (=minimum delay)
  #define DISABLE_INTERRUPTS()   __asm__("sim")                       ///< disable interrupt handling
  #define ENABLE_INTERRUPTS()    __asm__("rim")                       ///< enable interrupt handling
  #define TRIGGER_TRAP           __asm__("trap")                      ///< trigger a trap (=soft interrupt) e.g. for EMC robustness (see AN1015)
  #define WAIT_FOR_INTERRUPT()   __asm__("wfi")                       ///< stop code execution and wait for interrupt
  #define ENTER_HALT()           __asm__("halt")                      ///< put controller to HALT mode
  #define SW_RESET()             __asm__(".db 0x75")                  ///< reset via illegal opcode (works for all devices)

  // data type in bit fields
  #define BITS                   unsigned int                         ///< data type in bit structs (follow C90 standard)

// unsupported compiler -> stop
#else
  #error: compiler not supported
#endif


/*-------------------------------------------------------------------------
  FOR CONVENIENT PIN ACCESS
-------------------------------------------------------------------------*/

#define PIN0     0x01
#define PIN1     0x02
#define PIN2     0x04
#define PIN3     0x08
#define PIN4     0x10
#define PIN5     0x20
#define PIN6     0x40
#define PIN7     0x80


/*-------------------------------------------------------------------------
  DEVICE MEMORY (size in bytes)
-------------------------------------------------------------------------*/

// RAM
#define RAM_ADDR_START                0x000000
#define RAM_ADDR_END                  0x0007FF
#define RAM_SIZE                      2048
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

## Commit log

2021-01-17 inital docs commit
    [LQFP48.stp]
2021-02-02 Added more to the readme
    [bom.csv, halo-90.kicad_pcb]
2021-02-03 Moved earwire andded to docs
    [frenchEarwire.stp, halo-90.kicad_pcb, halo-90.kicad_sch]
2021-02-15 Docs improvment
    [halo-90.kicad_sch]
2021-02-15 Added case info
2021-02-17 Update readme.md
    Edits up to button
2021-02-17 Update readme.md
    Up until FDM printed
2021-02-22 Added spring pin part
2021-02-22 Added gifs to readme
    [halo-90.kicad_sch]
2021-02-22 Updated docs
    [halo-90.kicad_pcb]
2021-02-22 Added power profile
2021-02-23 Update readme.md
    From FDM Printed to GIF-boot
2021-02-25 Finalizing docs
    [bom.csv]
2025-01-27 Added case files
    [caseBot.STEP, caseTop.STEP, caseTop.STL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]
2025-03-12 Added earring case modified for FishHook ear wires
    [Case_Top_FishHook.STL, Cast_Bottom_FishHook.STL]

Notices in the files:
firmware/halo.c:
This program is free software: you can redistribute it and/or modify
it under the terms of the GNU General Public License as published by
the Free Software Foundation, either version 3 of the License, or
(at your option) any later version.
